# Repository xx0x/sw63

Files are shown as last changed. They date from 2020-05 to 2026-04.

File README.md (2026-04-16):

SW63 Electronic Watch

# Space Watch SW63

Sci-fi inspired electronic watch.

*MK4 in the development, out in 2026.*

## How to tell the time?

When the button is briefly pressed, SW63 tells you the time using a sequence of LED blinks. It's not a binary clock, it's inspired by the analog clock hands movement and uses quarters, halves and so on; similar to how people used to tell the time before the digital clock became popular.
  
**16:35**  
*half past - four - hours - and - five - minutes - PM*

**6:57**  
*three - minutes - to - whole - seven - hours*

Language can be changed in the watch menu to reflect the different ways different languages express the time ("half past five" in English is "half of six" in German etc).

See [LANGUAGES.md](./LANGUAGES.md) for the full list and examples.

## Controls

**Short press:** Show the time  
**Long press:** Enter Menu (setting the language and time)  
**Extra long press:** Enter Secret settings  
**Multiple short presses:** Show animation

*In Menu / Secret settings:*  
**Short press:** Change  
**Long press:** Confirm and go to next

## BOM (DIY Kits)

| Name | Part Number | Qty |
| --- | --- | --- |
| PCB with assembled SMD components | custom part | 1 |
| Red 5 mm LED | LL-503VD2E-V1-4D | 1 |
| Green 5 mm LED | LL-504PGD2E-G5-2B | 1 |
| Blue 5 mm LED | LL-504BD2E-B4-2B | 1 |
| Yellow 5 mm LED | N0Y64L35<br> L-53SYD<br> L-53SYDK | 1 |
| Yellow 3×2 mm LED | LL-234YD2Q-1B | 4 |
| Red 3 mm LED | FYL-3014LRD1A<br> FYL-3014SRT1A | 1 |
| Li-Po battery LP301020 or LP301120* | AKY0471<br> SparkFun 13852<br> SparkFun 25270 | 1 |
| CNC aluminium enclosure | custom part | 1 |
| Screw M1.6 length 4mm (hex socket)  | - | 4 |
| 18 mm watch spring bar | - | 2 |
| 18 mm watch strap | - | 1 |

> [!WARNING]
> \***Note:** Due to the shipping restrictions the Li-Po battery isn't part of the DIY Kit. Please provide your own 40 mAh battery with dimensions 20 mm × 11 mm × 3 mm (or smaller) with the integrated protection circuit.

## License

**Schematics, Hardware Designs**  
CERN-OHL-P-2.0

**Code**  
MIT

**Visual elements, Graphics, Documentation**  
CC BY-SA 4.0

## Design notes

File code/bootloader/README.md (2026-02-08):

# SW63 Bootloader

The bootloader is a separate project created using TinyUF2, source available in [my fork](https://github.com/xx0x/tinyuf2/tree/sw63-bootloader) inside `ports/stm32l0/boards/sw63`.

You can enter the bootloader holding the Button and pressing the Reset. Or double-pressing the Reset if you prefer. Press the Reset again to restart back to the Application.

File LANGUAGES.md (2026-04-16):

# Languages

People have been saying the time in different ways across different languages and countries. Today, many people simply read time in a digital form, like "seventeen twenty-five" or "six forty", mostly because digital clocks are everywhere on our phones, computers, and other screens.

Older time expressions (most significantly in Central Europe languages) were shaped much more by analog clocks and by the way their hands move around the dial. The main differences are which hour the quarter, half, and three-quarter landmarks belong to, and how the sentence is structured around them.

The examples below use 17:25 and 9:17 to show how the same moment is interpreted by each language family. Some of the explanations are a bit of a stretch, but the whole thing is meant as a small experiment. The PM marker, if used, is always last.

Feel free to suggest additional languages and improvements.

## 1. Czech, Slovak, Ukrainian, some east Germany regions

**17:25**  
*before - 5 - minutes - half of - 6 - hours - PM*

**9:17**  
*quarter of - 10 - hours - and - 2 - minutes*

Hour shifts: first quarter = +1 (next hour), half = +1 (next hour), third quarter = +1 (next hour)  
Example: Czech "za pět minut půl šesté"  
Literal meaning: "in five minutes half of six"

## 2. English

**17:25**  
*5 - minutes - before - half past - 5 hours - PM*

**9:17**  
*quarter past - 9 - hours - and - 2 - minutes*

Hour shifts: first quarter = +0 (current hour), half = +0 (current hour), third quarter = +1 (next hour)  
Example: "five minutes before half past five"

## 3. German, Dutch

**17:25**  
*5 - minutes - before - half of - 6 - hours - PM*

**9:17**  
*quarter past - 9 - hours - and - 2 - minutes*

Hour shift: first quarter = +0 (current hour), half = +1 (next hour), third quarter = +1 (next hour)  
Examples: German "fünf vor halb sechs", Dutch "vijf voor half zes"  
Literal meaning: "five before half six"

## 4. Polish

**17:25**  
*before - 5 - minutes - half of - 6 - hours - PM*

**9:17**  
*2 - minutes - after - quarter past - 9 - hours*

Hour shift: first quarter = +0 (current hour), half = +1 (next hour), third quarter = +1 (next hour)  
Example: "za pięć wpół do szóstej"  
Literal meaning: "in five, half to six"

## 5. Hungarian

**17:25**  
*5 - minutes - before - half of - 6 - hours - PM*

**9:17**  
*and - 2 - minutes - quarter of - 10 - hours*

Hour shift: first quarter = +1 (next hour), half = +1 (next hour), third quarter = +1 (next hour)  
Example: "öt perc múlva fél hat"  
Literal meaning: "in five minutes, half six"

## 6. Danish, Norwegian, Swedish, Finnish

**17:25**  
*5 - minutes - before - half of - 6 - hours - PM*

**9:17**  
*2 - minutes - after - quarter past - 9 - hours*

Hour shift: first quarter = +0 (current hour), half = +1 (next hour), third quarter = +1 (next hour)  
Example: Danish "fem i halv seks" / "fem minutter i halv seks"  
Literal meaning: approximately "five into half six"

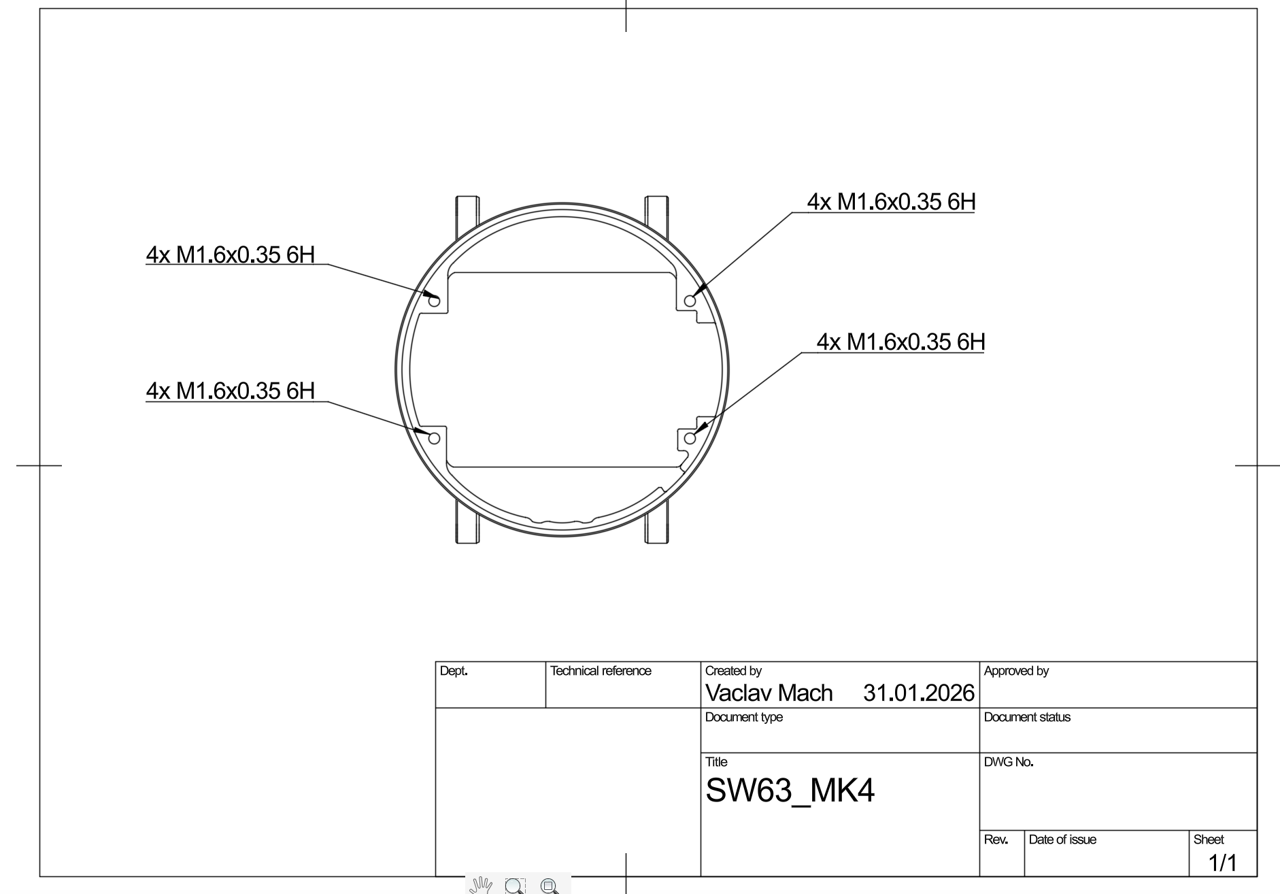
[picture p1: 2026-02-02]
case/sw63-case-threads.png

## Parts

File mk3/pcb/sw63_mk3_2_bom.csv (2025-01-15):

Comment | Designator | Footprint | LCSC Part #
 | PM | LED_3MM_ALT
 | HOURS | LED_5MM_BLUE
 | PLUS | LED_5MM_GREEN
 | MINUS | LED_5MM_RED
 | MINUTES | LED_5MM_YELLOW
1N5819 | D1 | SOD123
1u | C9 | CAPACITOR0603
2X3POGONO_VIA | SWD | 2X3_POGO_NO_VIA
2k | R9 | RESISTOR0603
4k7 | R5 R6 | RESISTOR0603
5k1 | R1 R2 R12 | RESISTOR0603
10k | R3 R4 R7 R8 R10 R13 R14 | RESISTOR0603
10u | C1 C2 C3 C4 | CAPACITOR0805
100n | C5 C6 C7 C8 C10 C11 | CAPACITOR0603
2302 | Q2 | SOT23
2305 | Q1 | SOT23
ATSAMD21E18A-MU | U1 | QFN50P500X500X100-33N
BSMD0805-050-24V | F1 | PTC0805
DS3231MZ+ | U2 | SO8
GT-USB-7070C | J1 | USB-C_FULL_SMT_WS
KSC321JLFS | SW1 | KSC3XXJ
LED_RECT-3.2X2 | DOWN LEFT RIGHT UP | LED_RECT_3.2X2
LED_SMT_1206 | LD1 LD2 LD3 LD4 LD5 LD6 LD7 LD8 LD9 LD10 LD11 LD12 | LED_1206
MCP73832T-2ACI/OT | U7 | SOT23-5
ME6211C33M5G-N | U6 | SOT23-5
RB521S | D2 D3 D4 D5 | SOD523
SMALL_NC | SJ1 | SMALL_NC_NOSILK
TEMT6200FX01 | Q4 | TEMT6200FX01
TEST_PIN_LARGE | B+ B- | TEST_PIN_2.0
TLC5916IPW | U3 U4 U5 | TSSOP16
TSC4A 160gf-WZ 016 | SW2 | EVQ-P7J01P

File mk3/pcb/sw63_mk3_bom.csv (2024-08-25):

Comment | Designator | Footprint | LCSC Part #
 | PM | LED_3MM_ALT
 | HOURS | LED_5MM_BLUE
 | PLUS | LED_5MM_GREEN
 | MINUS | LED_5MM_RED
 | MINUTES | LED_5MM_YELLOW
1N5819 | D1 | SOD123
1u | C9 | CAPACITOR0603
2X3POGONO_VIA | SWD | 2X3_POGO_NO_VIA
2k | R9 | RESISTOR0603
4k7 | R5 R6 | RESISTOR0603
5k1 | R1 R2 R12 | RESISTOR0603
10k | R3 R4 R7 R8 R10 R11 R13 R14 | RESISTOR0603
10u | C1 C2 C3 C4 | CAPACITOR0805
100n | C5 C6 C7 C8 C10 C11 | CAPACITOR0603
500mA | F1 | PTC0805
ATSAMD21E18A-MU | U1 | QFN50P500X500X100-33N
BC817S | Q2 Q3 | SOT23
DS3231MZ+ | U2 | SO8
EVQ-P7J01P | SW2 | EVQ-P7J01P
KSC321JLFS | SW1 | KSC3XXJ
LED_RECT-3.2X2 | DOWN LEFT RIGHT UP | LED_RECT_3.2X2
LED_SMT_1206 | LD1 LD2 LD3 LD4 LD5 LD6 LD7 LD8 LD9 LD10 LD11 LD12 | LED_1206
LGE2305 | Q1 | SOT23
MCP73832T-2ACI/OT | U7 | SOT23-5
MIC5504YM5-TR | U6 | SOT23-5
TEMT6200FX01 | Q4 | TEMT6200FX01
TEST_PIN_LARGE | B+ B- | TEST_PIN_2.0
TLC5916IPW | U3 U4 U5 | TSSOP16
USB-C_2.0_SMT | J1 | USB-C_FULL_SMT

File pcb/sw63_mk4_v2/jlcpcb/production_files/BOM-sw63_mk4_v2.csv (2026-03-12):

Comment | Designator | Footprint | LCSC | Quantity
0603L020/30XR | F1 | Fuse_0603_1608Metric | C20608677 | 1
100k | R11,R12 | R_0402_1005Metric | C25741 | 2
100n | C10,C11,C12,C4,C5,C6,C9 | C_0402_1005Metric | C1525 | 7
10k | R4,R5,R6,R7 | R_0402_1005Metric | C25744 | 4
10u | C1,C2,C3,C7,C8 | C_0402_1005Metric | C315248 | 5
220k | R13 | R_0402_1005Metric | C25767 | 1
22k | R14,R15,R16,R3 | R_0402_1005Metric | C25768 | 4
2k | R8 | R_0402_1005Metric | C4109 | 1
5k1 | R1,R10,R2,R9 | R_0402_1005Metric | C25905 | 4
DIO5518BST5 | U1 | SOT-23-5 | C38066 | 1
DMG2302U-7 | Q2 | SOT-23 | C96613 | 1
DMG2305UX-7 | Q1 | SOT-23 | C150470 | 1
DS3231MZ | U6 | SOIC-8_3.9x4.9mm_P1.27mm | C107410 | 1
GT-USB-7070C | J1 | GT-USB-7070C | C5446864 | 1
KSC321J LFS | SW1 | SW_Push_1P1T_NO_CK_KSC3xxJ | C2798494 | 1
LED | D1,D10,D11,D12,D2,D3,D4,D5,D6,D7,D8,D9 | LED_1206_W | C965828 | 12
MCP1711T-3.3I/OT | U2 | SOT-23-5 | C79527 | 1
MS2A40LWS | D22 | D_SOD-323 | C7380001 | 1
STM32L052K8Ux | U7 | QFN-32-1EP_5x5mm_P0.5mm_EP3.45x3.45mm | C1342049 | 1
TEMT6200FX01 | Q3 | TEMT6200FX01 | C143695 | 1
TLC5916IPWR | U3,U4,U5 | TSSOP-16_4.4x5mm_P0.65mm | C193571 | 3
EVQ-P7J01P | SW2 | SW_SPST_EVQP7A | C2828254 | 1
LED | D14 | LED_D5.0mm_B |  | 1
LED | D16 | LED_D5.0mm_R |  | 1
LED | D21 | LED_D3.0mm_R |  | 1
LED | D20 | LED_W3.0mm_H2.0mm_Y |  | 1
LED | D18 | LED_W3.0mm_H2.0mm_Y |  | 1
LED | D13 | LED_D5.0mm_Y |  | 1
LED | D15 | LED_D5.0mm_G |  | 1
LED | D19 | LED_W3.0mm_H2.0mm_Y |  | 1
Conn_01x02 | J3 | BAT |  | 1
LED | D17 | LED_W3.0mm_H2.0mm_Y |  | 1

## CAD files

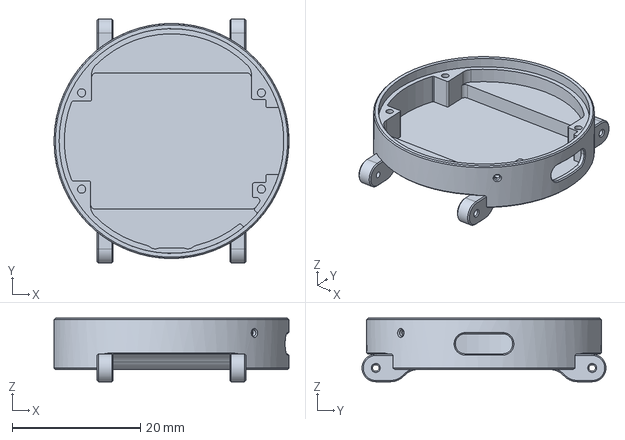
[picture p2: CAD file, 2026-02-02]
case/sw63-case.step
36.6 x 38.0 x 9.90 mm

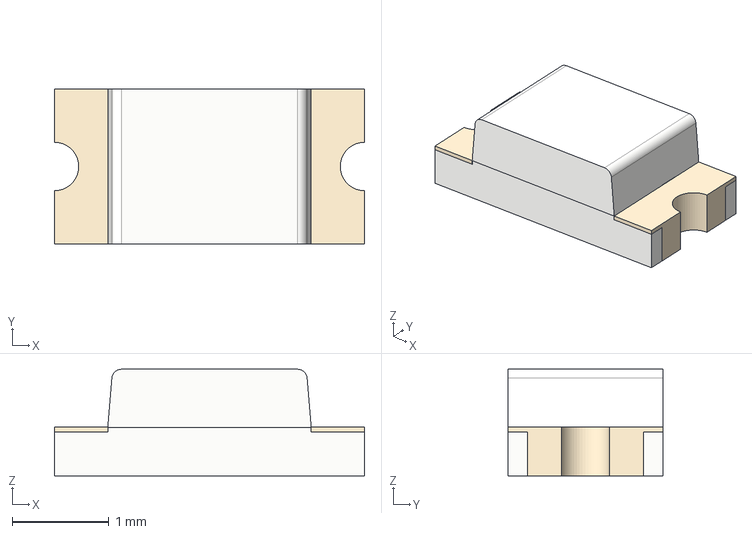
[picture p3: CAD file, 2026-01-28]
pcb/sw63_mk4_v2/3d_models/LED_1206_W.step
3.20 x 1.60 x 1.10 mm

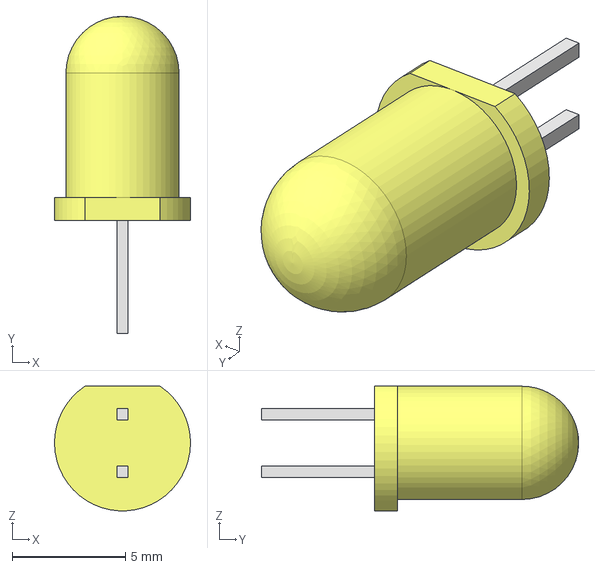
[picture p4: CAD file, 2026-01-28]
pcb/sw63_mk4_v2/3d_models/LED_5mm_Y.step
6.00 x 14.0 x 5.49 mm

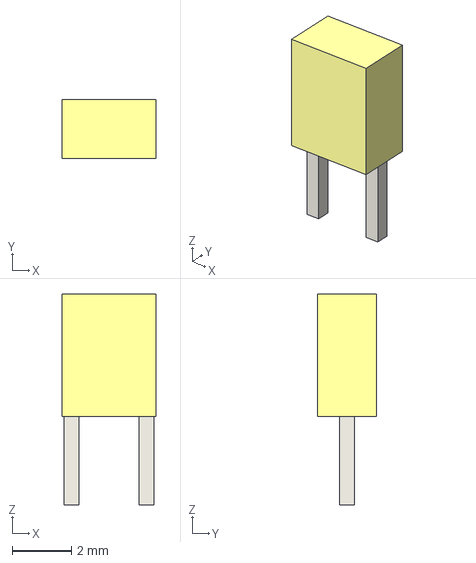
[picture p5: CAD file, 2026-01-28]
pcb/sw63_mk4_v2/3d_models/LED_2x3mm_Y.step
3.20 x 2.00 x 7.15 mm

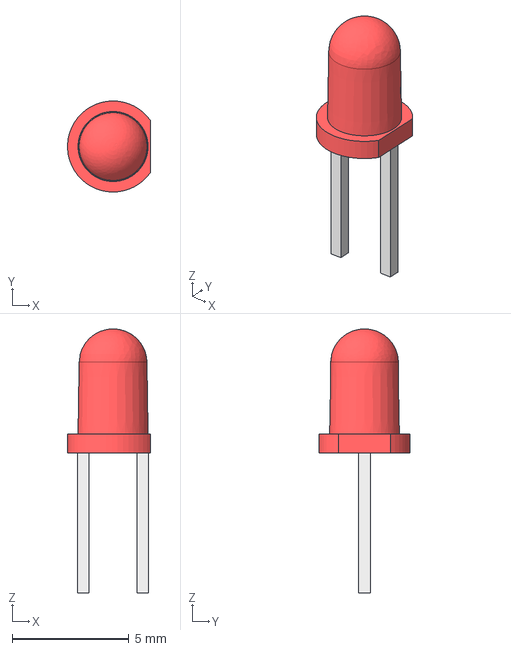
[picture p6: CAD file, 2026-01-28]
pcb/sw63_mk4_v2/3d_models/LED_3mm_R.step
3.55 x 3.90 x 11.3 mm
Деталь1
Деталь2 x 2

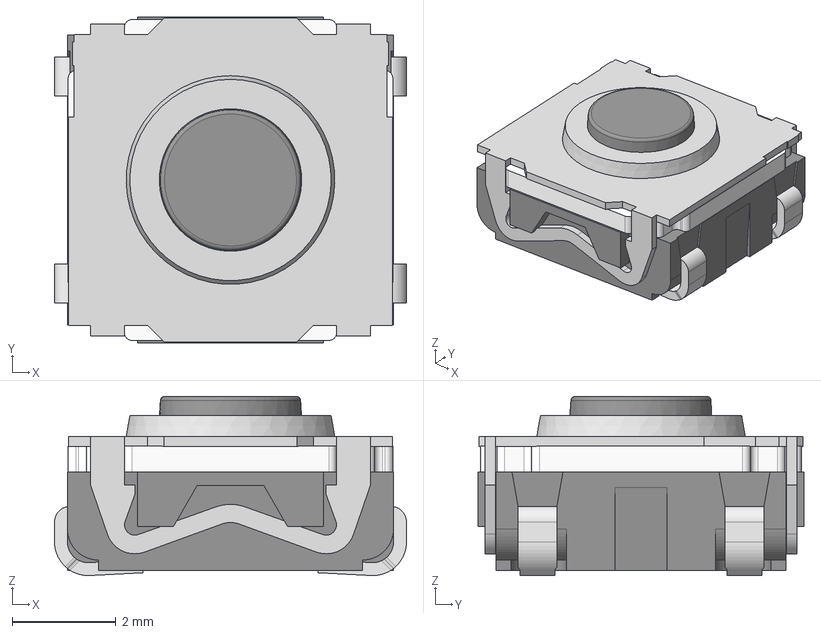
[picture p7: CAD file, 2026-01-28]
pcb/sw63_mk4_v2/3d_models/KSC3XXJ.step
6.80 x 6.30 x 3.46 mm
KSC3_body
KSC3_button
KSC3_cover
KSC31J_pin x 4

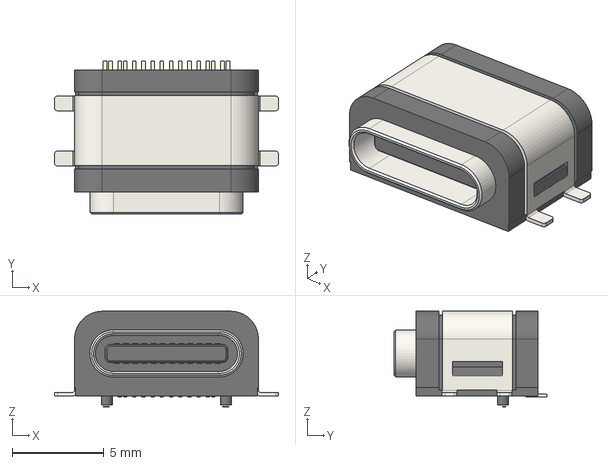
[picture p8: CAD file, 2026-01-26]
pcb/sw63_mk4_v2/3d_models/GT-USB-7070C.step
12.2 x 8.35 x 5.20 mm

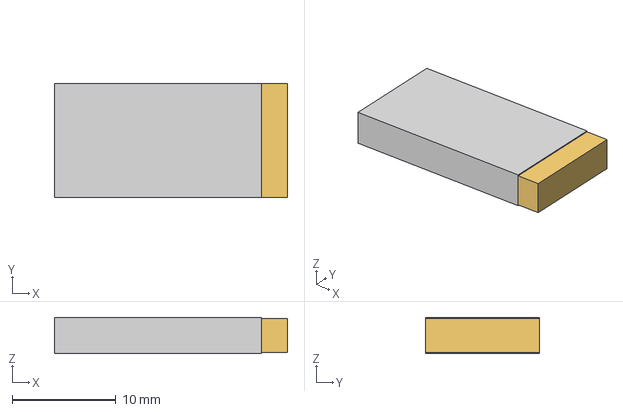
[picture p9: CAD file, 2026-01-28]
pcb/sw63_mk4_v2/3d_models/LP301020.step
22.5 x 11.0 x 3.50 mm

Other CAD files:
pcb/sw63_mk4_v2/3d_models/LED_5mm_G.step
pcb/sw63_mk4_v2/3d_models/LED_5mm_R.step
pcb/sw63_mk4_v2/3d_models/LED_5mm_B.step

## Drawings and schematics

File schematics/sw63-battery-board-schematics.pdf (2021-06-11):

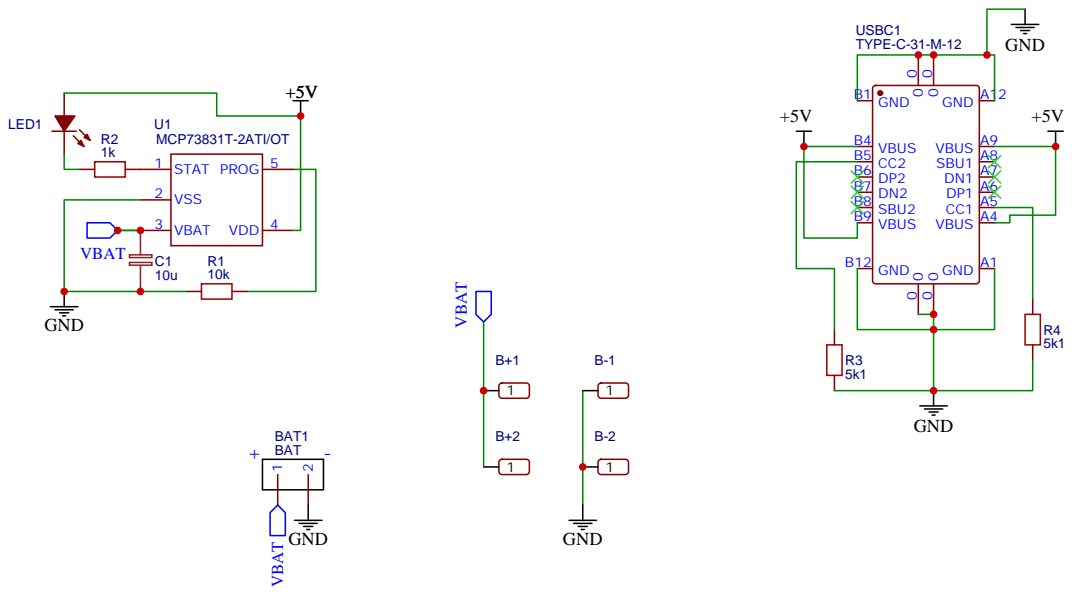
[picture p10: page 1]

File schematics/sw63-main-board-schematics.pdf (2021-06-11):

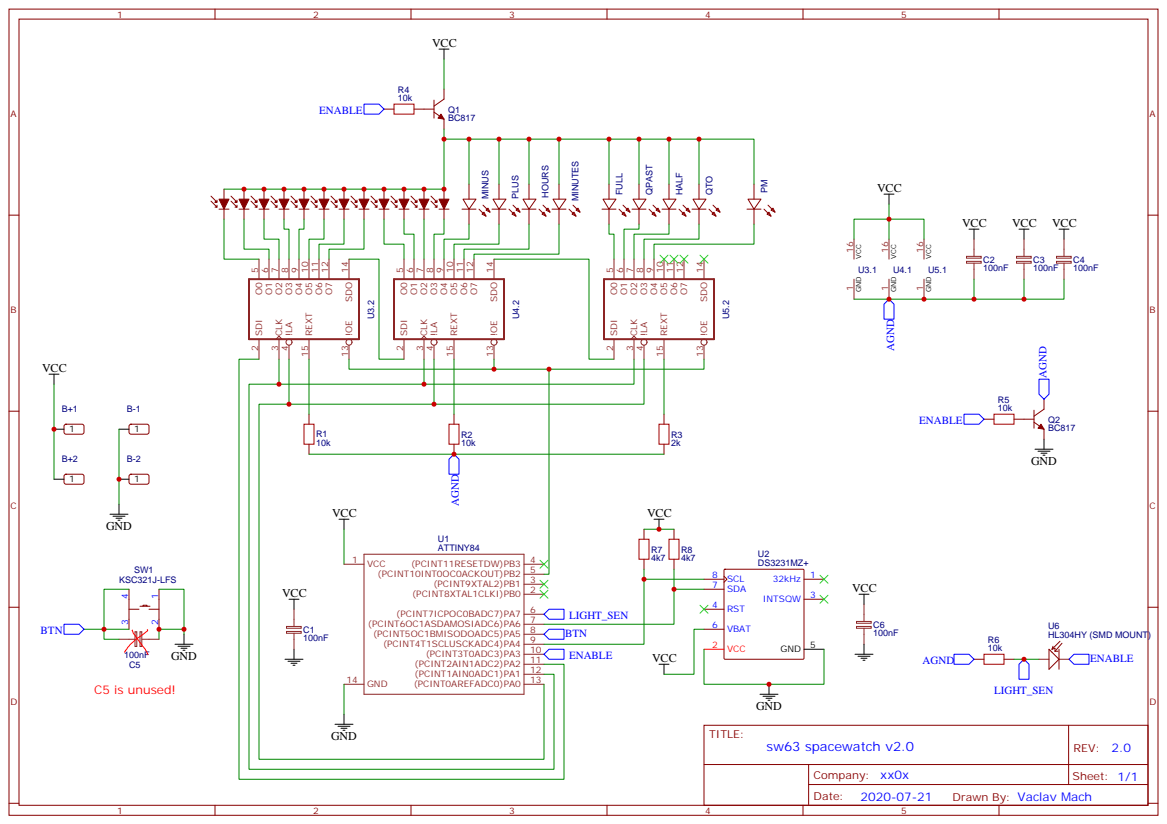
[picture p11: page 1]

Drawn By: Vaclav Mach

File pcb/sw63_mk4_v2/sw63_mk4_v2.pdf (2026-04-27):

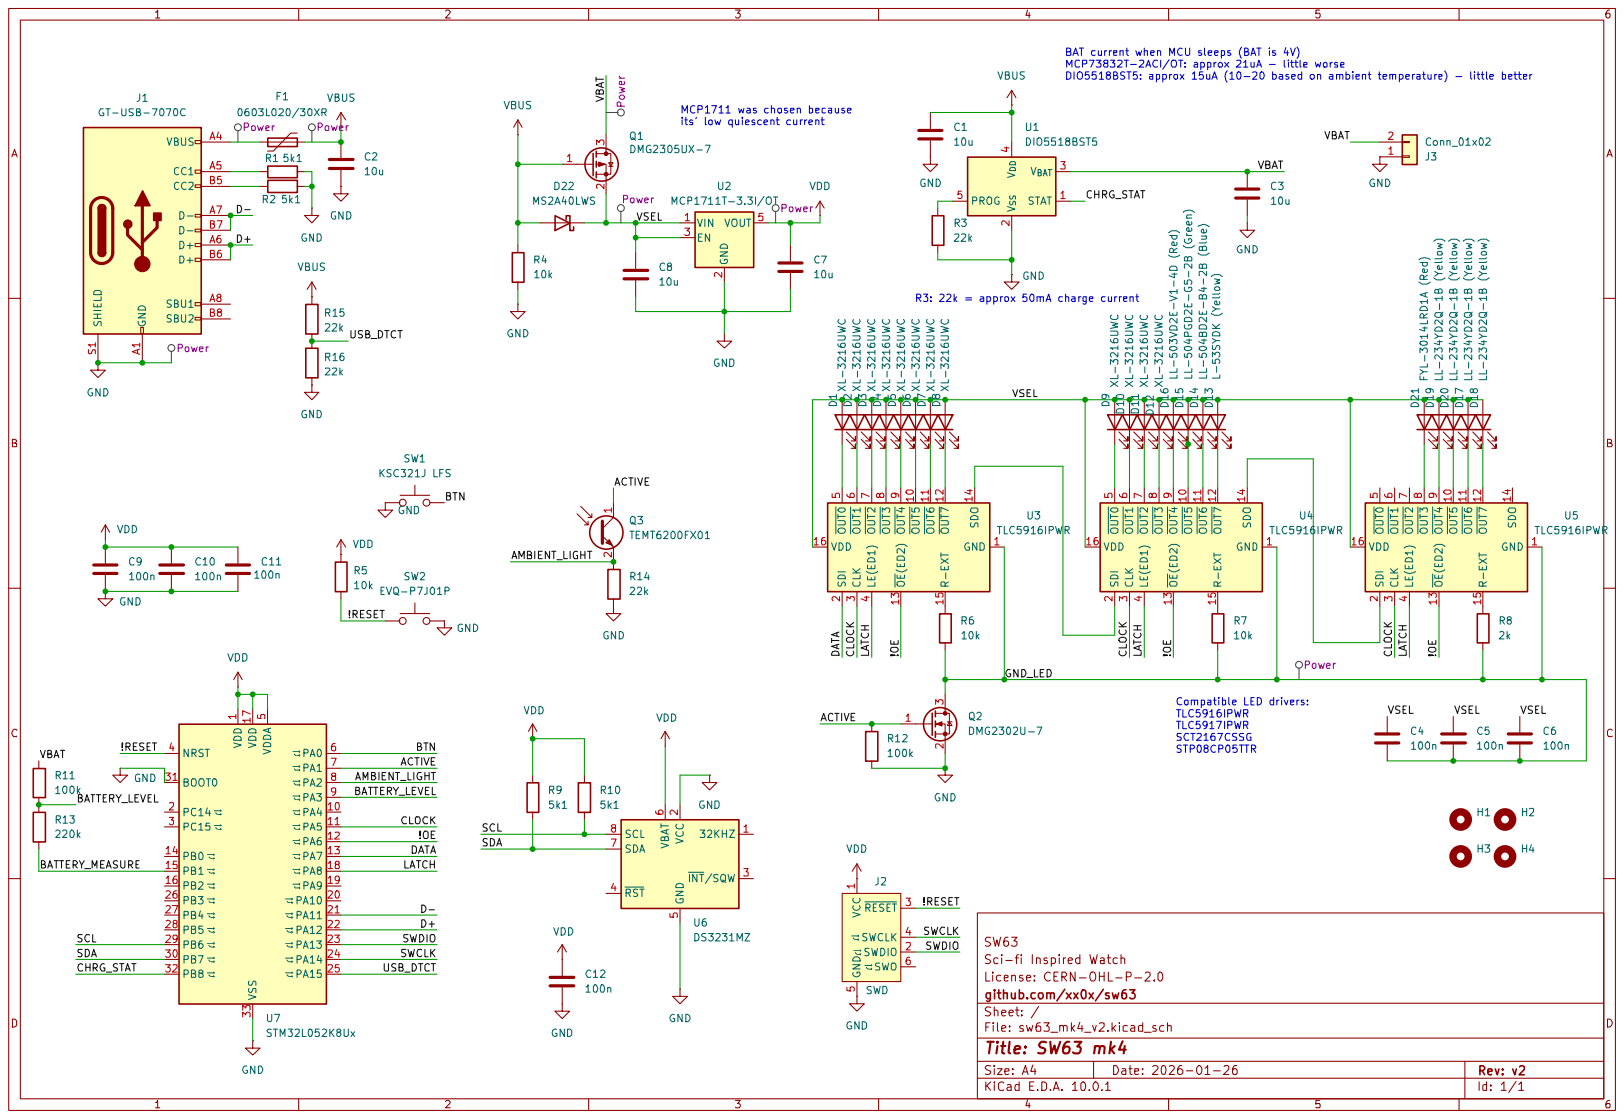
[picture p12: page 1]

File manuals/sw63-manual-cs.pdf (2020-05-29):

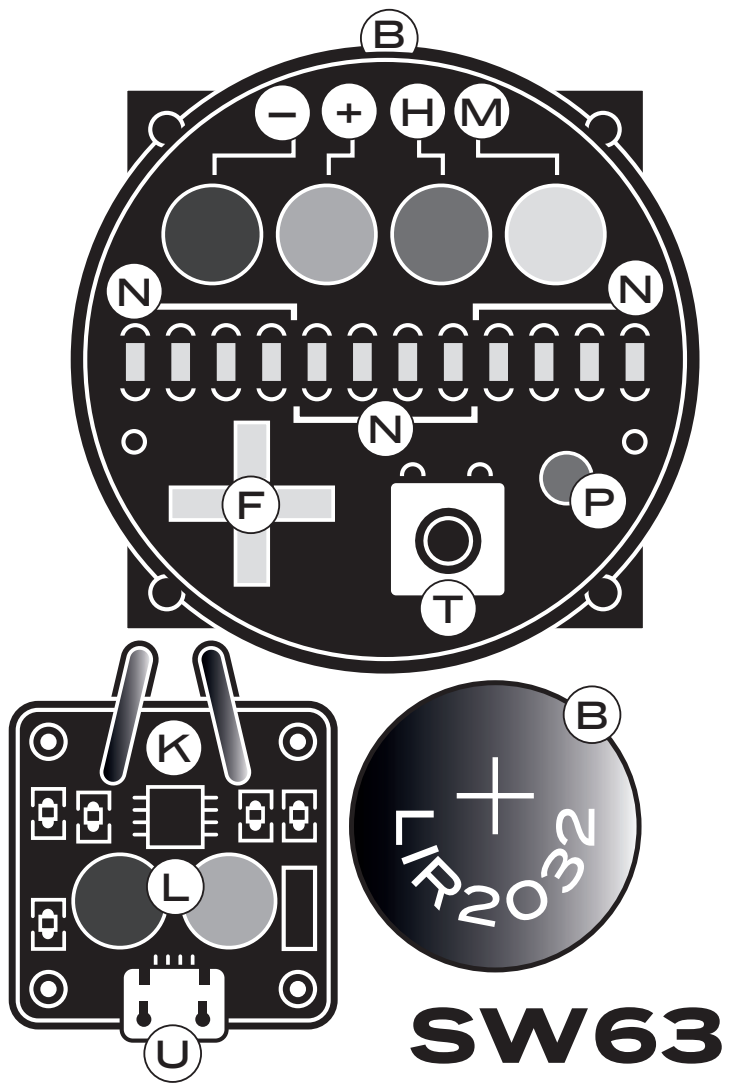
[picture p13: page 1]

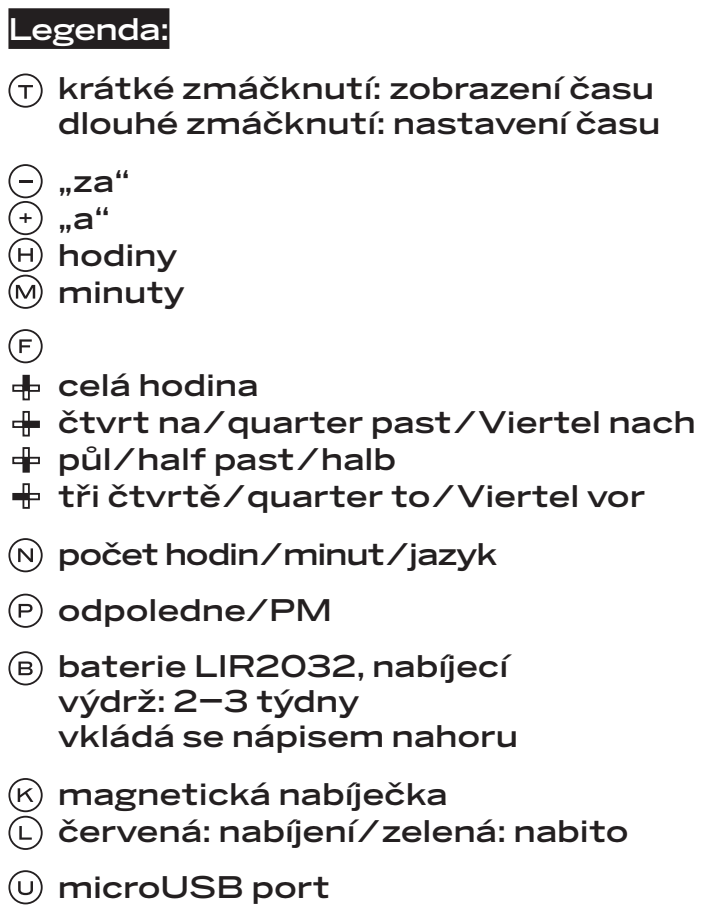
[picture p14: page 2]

Legenda:
krátké zmáčknutí: zobrazení času
dlouhé zmáčknutí: nastavení času
hodiny
minuty

celá hodina
čtvrt na/quarter past/Viertel nach
půl/half past/halb
tři čtvrtě/quarter to/Viertel vor
počet hodin/minut/jazyk
odpoledne/PM
baterie LIR2032, nabíjecí
výdrž: 2–3 týdny
vkládá se nápisem nahoru
magnetická nabíječka
červená: nabíjení/zelená: nabito
microUSB port

SW63 - SPACEWATCH
Hodinky SPACEWATCH zobrazují čas pomocí lidské řeči. 17:28 se zobrazí jako: „za–dvě–minuty–půl–šesté–odpoledne“

Odolnost a údržba:
Hodinkám nevadí drobné kapky od mytí rukou nebo slabého deště, při větším namočení je vhodné vytáhnout baterii
a hodinky nechat vyschnout.
Zaprášené nebo jinak znečištěné hodinky lze otřít vatovou štětičkou namočenou v destilované vodě.

Intro animace:
Pro rozblikání hodinek několikrát po sobě rychle zmáčknout .
Na konci intro animace zabliká aktuálně zvolený jazyk, poté se zobrazí čas.

xx0x.cz
info@xx0x.cz
@xx0x.cz

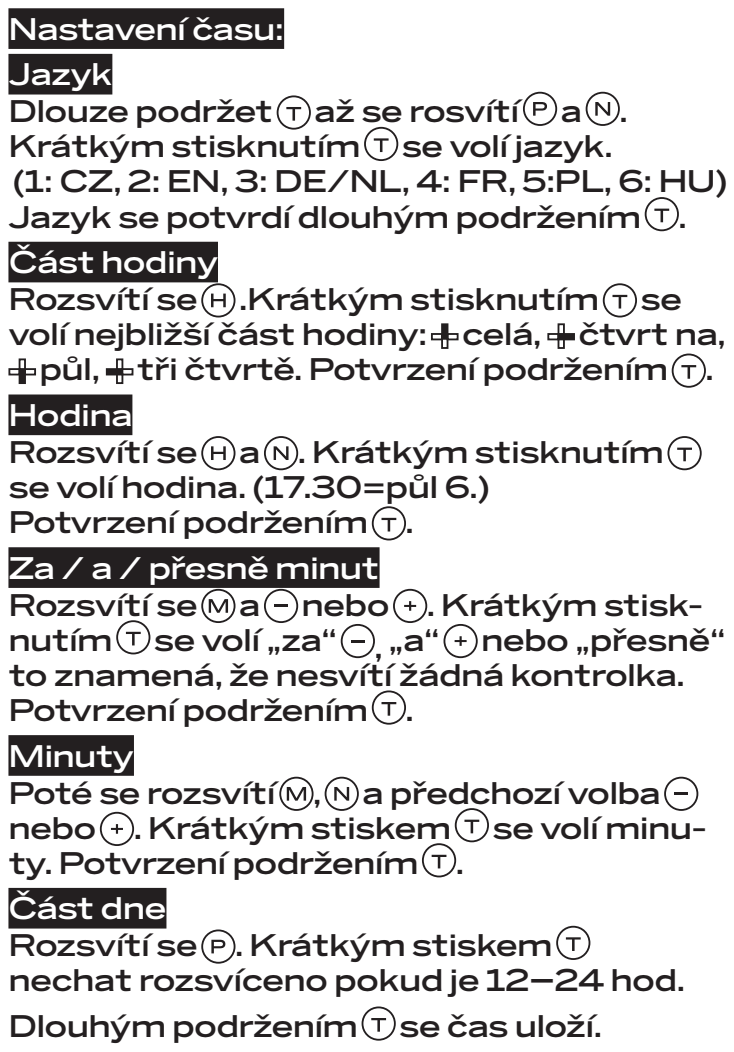
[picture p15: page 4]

Nastavení času:
Jazyk
Dlouze podržet až se rosvítí a .
Krátkým stisknutím se volí jazyk.
Jazyk se potvrdí dlouhým podržením .
Část hodiny
Rozsvítí se .Krátkým stisknutím se
volí nejbližší část hodiny: celá, čtvrt na,
půl, tři čtvrtě. Potvrzení podržením .
Hodina
Rozsvítí se a . Krátkým stisknutím
se volí hodina. (17.30=půl 6.)
Potvrzení podržením .
Za / a / přesně minut
Rozsvítí se a nebo . Krátkým stisk-
nutím se volí „za“ , „a“ nebo „přesně“
to znamená, že nesvítí žádná kontrolka.
Minuty
Poté se rozsvítí , a předchozí volba
nebo . Krátkým stiskem se volí minu-
ty. Potvrzení podržením .
Část dne
Rozsvítí se . Krátkým stiskem
nechat rozsvíceno pokud je 12–24 hod.
Dlouhým podržením se čas uloží.

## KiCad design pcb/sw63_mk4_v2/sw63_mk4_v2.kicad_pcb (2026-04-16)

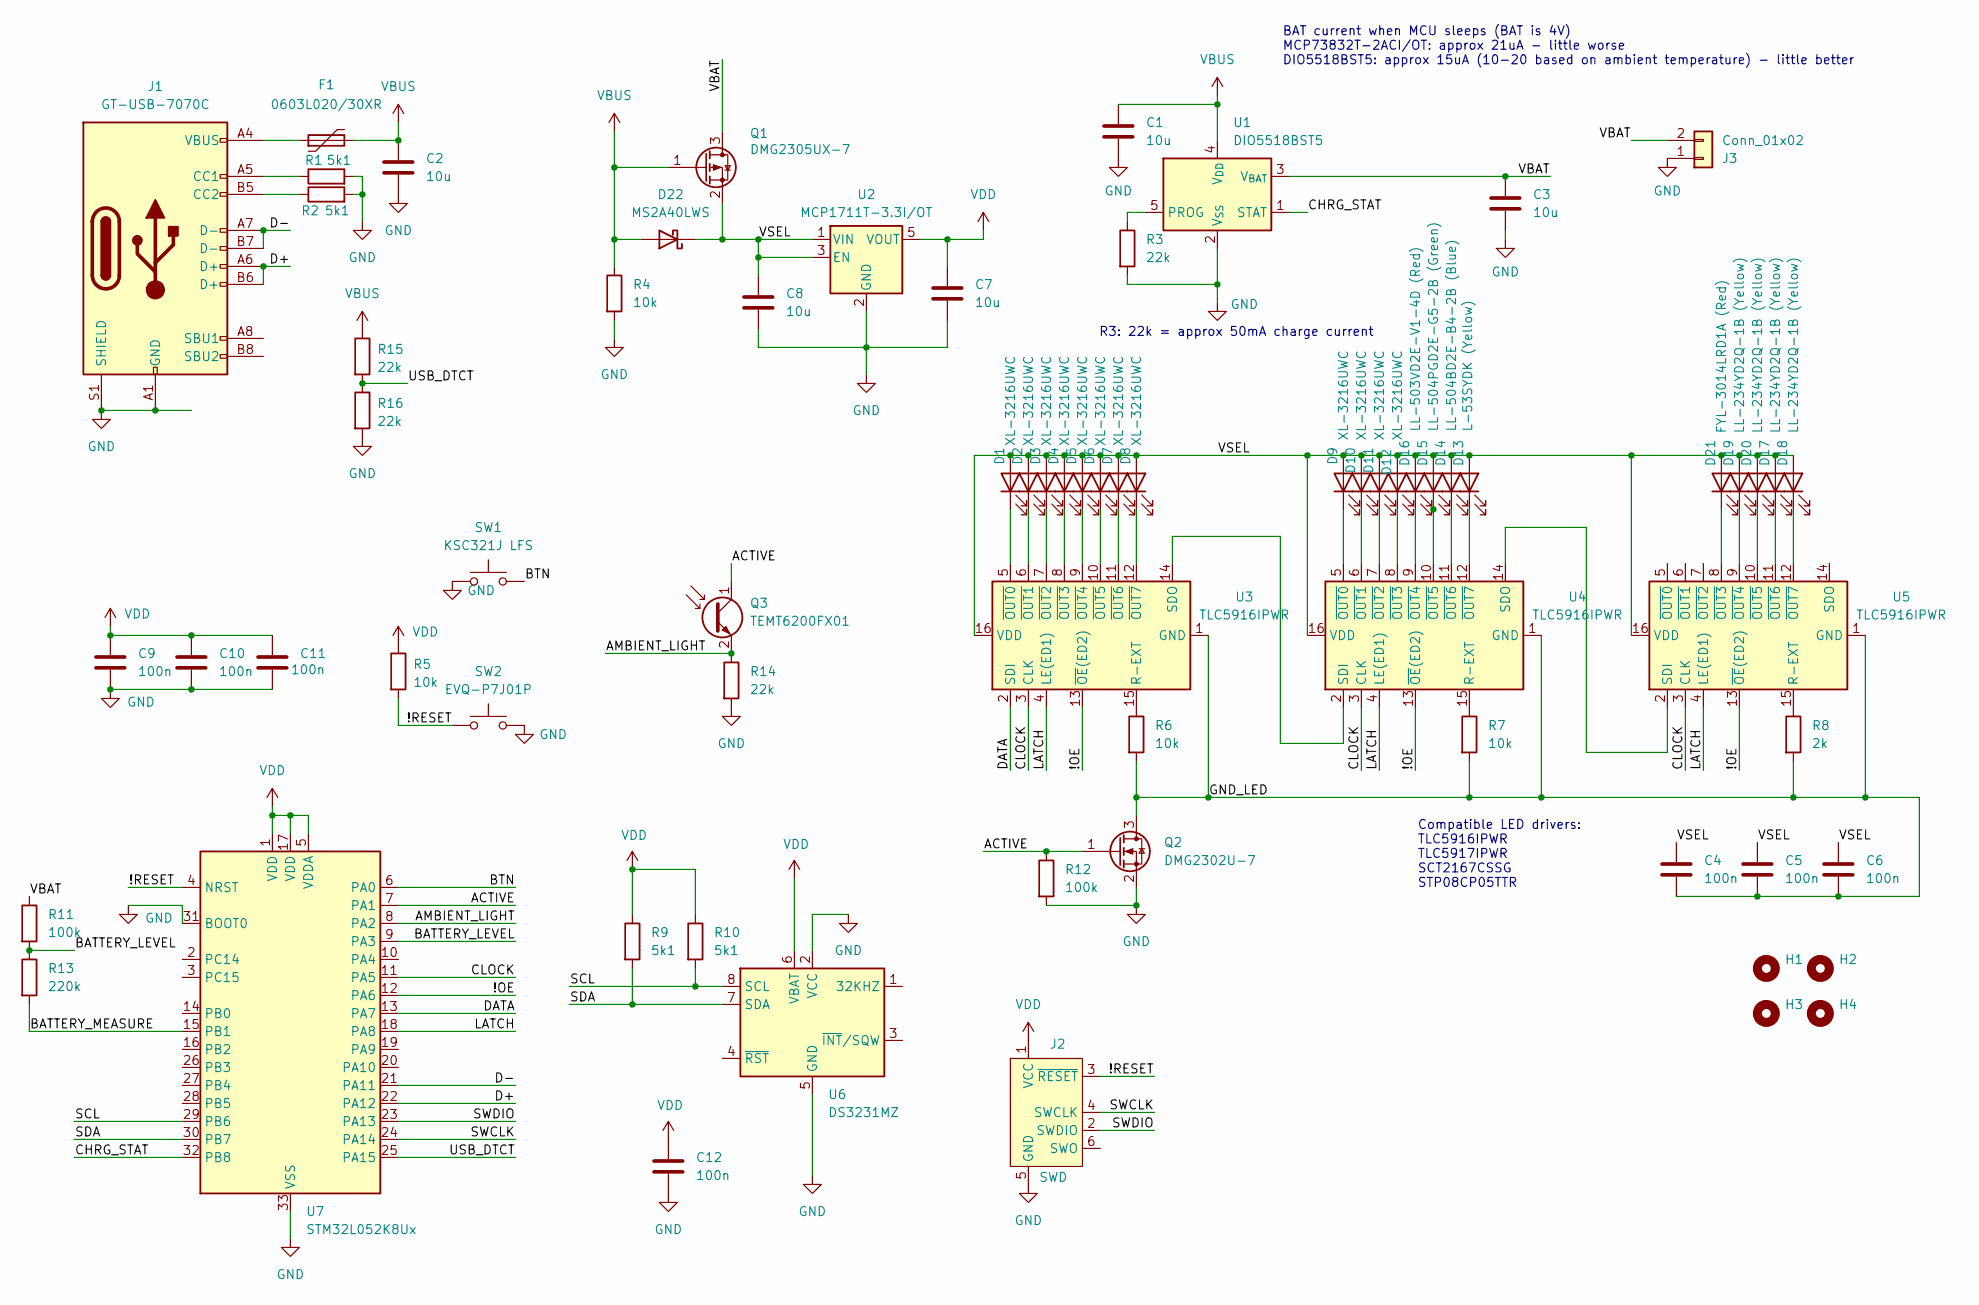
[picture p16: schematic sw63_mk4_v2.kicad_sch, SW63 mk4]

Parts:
C1, C2, C3, C7, C8: 10u; C_0402_1005Metric; LCSC C315248
C4, C5, C6, C9, C10, C11, C12: 100n; C_0402_1005Metric; LCSC C1525
D1, D2, D3, D4, D5, D6, D7, D8, D9, D10, D11, D12: XL-3216UWC; LED_1206_W; LCSC C965828
D13: L-53SYDK (Yellow); LED_D5.0mm_Y
D14: LL-504BD2E-B4-2B (Blue); LED_D5.0mm_B
D15: LL-504PGD2E-G5-2B (Green); LED_D5.0mm_G
D16: LL-503VD2E-V1-4D (Red); LED_D5.0mm_R
D17, D18, D19, D20: LL-234YD2Q-1B (Yellow); LED_W3.0mm_H2.0mm_Y
D21: FYL-3014LRD1A (Red); LED_D3.0mm_R
D22: MS2A40LWS; D_SOD-323; LCSC C7380001
F1: 0603L020/30XR; Fuse_0603_1608Metric; LCSC C20608677
H1, H2, H3, H4: MountingHole; MountingHole_1.6mm
J1: GT-USB-7070C; LCSC C5446864
J2: SWD; SWD_2x03_SMD
J3: Conn_01x02; BAT
Q1: DMG2305UX-7; SOT-23; LCSC C150470
Q2: DMG2302U-7; SOT-23
Q3: TEMT6200FX01; LCSC C143695
R1, R2, R9, R10: 5k1; R_0402_1005Metric; LCSC C25905
R3, R14, R15, R16: 22k; R_0402_1005Metric; LCSC C25768
R4, R5, R6, R7: 10k; R_0402_1005Metric; LCSC C25744
R8: 2k; R_0402_1005Metric; LCSC C4109
R11, R12: 100k; R_0402_1005Metric; LCSC C25741
R13: 220k; R_0402_1005Metric; LCSC C25767
SW1: KSC321J LFS; SW_Push_1P1T_NO_CK_KSC3xxJ; LCSC C2798494
SW2:  EVQ-P7J01P; SW_SPST_EVQP7A; LCSC C2828254
U1: DIO5518BST5; SOT-23-5; LCSC C38066
U2: MCP1711T-3.3I/OT; SOT-23-5; LCSC C79527
U3, U4, U5: TLC5916IPWR; TSSOP-16_4.4x5mm_P0.65mm; LCSC C193571
U6: DS3231MZ; SOIC-8_3.9x4.9mm_P1.27mm; LCSC C107410
U7: STM32L052K8Ux; QFN-32-1EP_5x5mm_P0.5mm_EP3.45x3.45mm; LCSC C1342049

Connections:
/!OE: U3.13 (~OE(ED2)), U4.13 (~OE(ED2)), U5.13 (~OE(ED2)), U7.12 (PA6)
/!RESET: J2.3 (~RESET), R5.2, SW2.1, U7.4 (NRST)
/ACTIVE: Q2.1 (G), Q3.1 (C), R12.1, U7.7 (PA1)
/AMBIENT_LIGHT: Q3.2 (E), R14.1, U7.8 (PA2)
/BATTERY_LEVEL: R11.2, R13.1, U7.9 (PA3)
/BATTERY_MEASURE: R13.2, U7.15 (PB1)
/BTN: SW1.2, U7.6 (PA0)
/CHRG_STAT: U1.1 (STAT), U7.32 (PB8)
/CLOCK: U3.3 (CLK), U4.3 (CLK), U5.3 (CLK), U7.11 (PA5)
/D+: J1.A6 (D+), J1.B6 (D+), U7.22 (PA12)
/D-: J1.A7 (D-), J1.B7 (D-), U7.21 (PA11)
/DATA: U3.2 (SDI), U7.13 (PA7)
/GND_LED: C4.2, C5.2, C6.2, Q2.3 (D), R6.2, R7.2, R8.2, U3.1 (GND), U4.1 (GND), U5.1 (GND)
/LATCH: U3.4 (LE(ED1)), U4.4 (LE(ED1)), U5.4 (LE(ED1)), U7.18 (PA8)
/SCL: R10.2, U6.8 (SCL), U7.29 (PB6)
/SDA: R9.2, U6.7 (SDA), U7.30 (PB7)
/SWCLK: J2.4 (SWCLK), U7.24 (PA14)
/SWDIO: J2.2 (SWDIO), U7.23 (PA13)
/USB_DTCT: R15.2, R16.1, U7.25 (PA15)
/VBAT: C3.1, J3.2, Q1.3 (D), R11.1, U1.3 (V_{BAT})
/VSEL: C4.1, C5.1, C6.1, C8.1, D1.2 (A), D2.2 (A), D3.2 (A), D4.2 (A), D5.2 (A), D6.2 (A), D7.2 (A), D8.2 (A), D9.2 (A), D10.2 (A), D11.2 (A), D12.2 (A), D13.2 (A), D14.2 (A), D15.2 (A), D16.2 (A), D17.2 (A), D18.2 (A), D19.2 (A), D20.2 (A), D21.2 (A), D22.1 (K), Q1.2 (S), U2.1 (VIN), U2.3 (EN), U3.16 (VDD), U4.16 (VDD), U5.16 (VDD)
GND: C1.2, C2.2, C3.2, C7.2, C8.2, C9.2, C10.2, C11.2, C12.2, J1.A1 (GND), J1.A12 (GND), J1.B1 (GND), J1.B12 (GND), J1.S1 (SHIELD), J2.5 (GND), J3.1, Q2.2 (S), R1.2, R2.2, R3.2, R4.2, R12.2, R14.2, R16.2, SW1.1, SW2.2, U1.2 (V_{SS}), U2.2 (GND), U6.2 (VCC), U6.5 (GND), U7.31 (BOOT0), U7.33 (VSS)
unnamed: D1.1 (K), U3.5 (~OUT0)
unnamed: D2.1 (K), U3.6 (~OUT1)
unnamed: D3.1 (K), U3.7 (~OUT2)
unnamed: D4.1 (K), U3.8 (~OUT3)
unnamed: D5.1 (K), U3.9 (~OUT4)
unnamed: D6.1 (K), U3.10 (~OUT5)
unnamed: D7.1 (K), U3.11 (~OUT6)
unnamed: D8.1 (K), U3.12 (~OUT7)
unnamed: D9.1 (K), U4.5 (~OUT0)
unnamed: D10.1 (K), U4.6 (~OUT1)
unnamed: D11.1 (K), U4.7 (~OUT2)
unnamed: D12.1 (K), U4.8 (~OUT3)
unnamed: D13.1 (K), U4.12 (~OUT7)
unnamed: D14.1 (K), U4.11 (~OUT6)
unnamed: D15.1 (K), U4.10 (~OUT5)
unnamed: D16.1 (K), U4.9 (~OUT4)
unnamed: D17.1 (K), U5.11 (~OUT6)
unnamed: D18.1 (K), U5.12 (~OUT7)
unnamed: D19.1 (K), U5.9 (~OUT4)
unnamed: D20.1 (K), U5.10 (~OUT5)
unnamed: D21.1 (K), U5.8 (~OUT3)
unnamed: F1.1, J1.A4 (VBUS), J1.A9 (VBUS), J1.B4 (VBUS), J1.B9 (VBUS)
unnamed: J1.A5 (CC1), R1.1
unnamed: J1.B5 (CC2), R2.1
unnamed: R3.1, U1.5 (PROG)
unnamed: R6.1, U3.15 (R-EXT)
unnamed: U3.14 (SDO), U4.2 (SDI)
unnamed: R7.1, U4.15 (R-EXT)
unnamed: U4.14 (SDO), U5.2 (SDI)
unnamed: R8.1, U5.15 (R-EXT)
VBUS: C1.1, C2.1, D22.2 (A), F1.2, Q1.1 (G), R4.1, R15.1, U1.4 (V_{DD})
VDD: C7.1, C9.1, C10.1, C11.1, C12.1, J2.1 (VCC), R5.1, R9.1, R10.1, U2.5 (VOUT), U6.6 (VBAT), U7.1 (VDD), U7.5 (VDDA), U7.17 (VDD)

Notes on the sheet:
BAT current when MCU sleeps (BAT is 4V) MCP73832T-2ACI/OT: approx 21uA - little worse DIO5518BST5: approx 15uA (10-20 based on ambient temperature) - little better
R3: 22k = approx 50mA charge current
Compatible LED drivers: TLC5916IPWR TLC5917IPWR SCT2167CSSG STP08CP05TTR

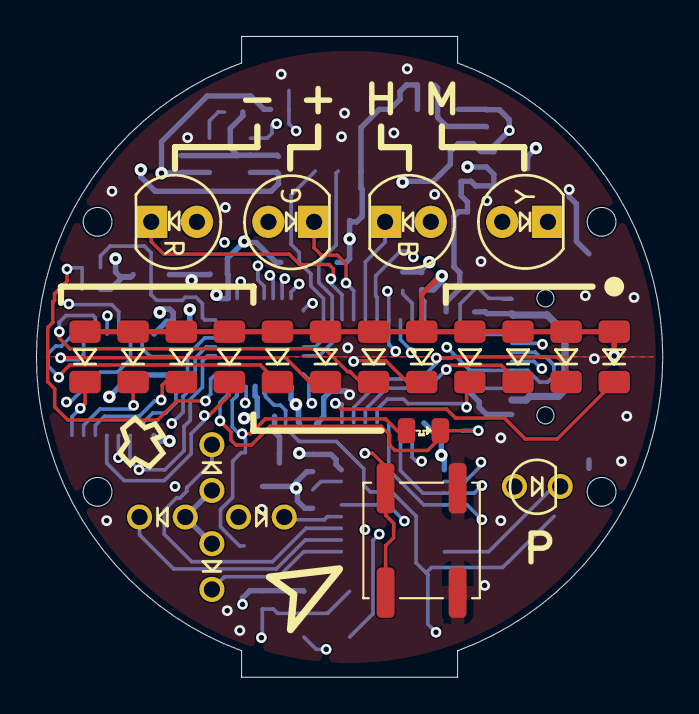
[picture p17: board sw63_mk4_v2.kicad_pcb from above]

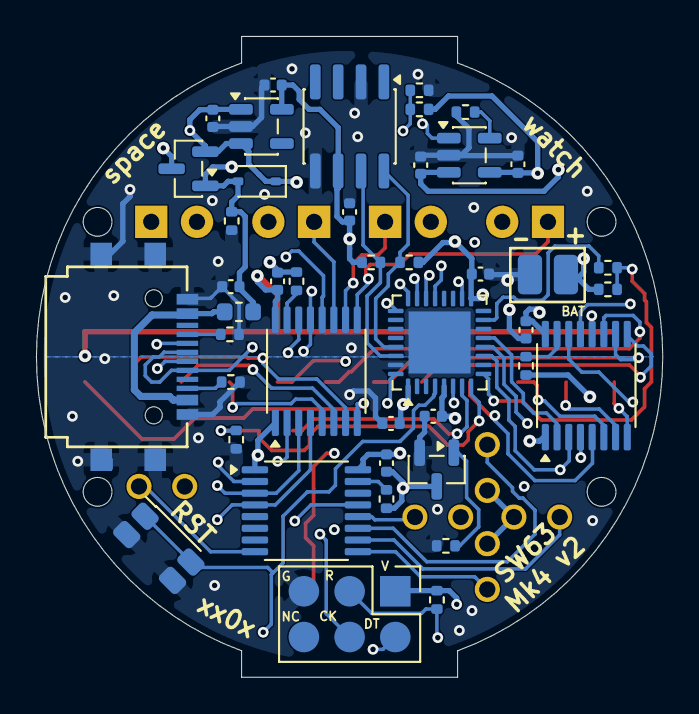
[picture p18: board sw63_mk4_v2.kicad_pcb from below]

Board: 4 copper layers, 34.8 x 35.6 mm, 70 parts (43 on the bottom side), 54 nets.

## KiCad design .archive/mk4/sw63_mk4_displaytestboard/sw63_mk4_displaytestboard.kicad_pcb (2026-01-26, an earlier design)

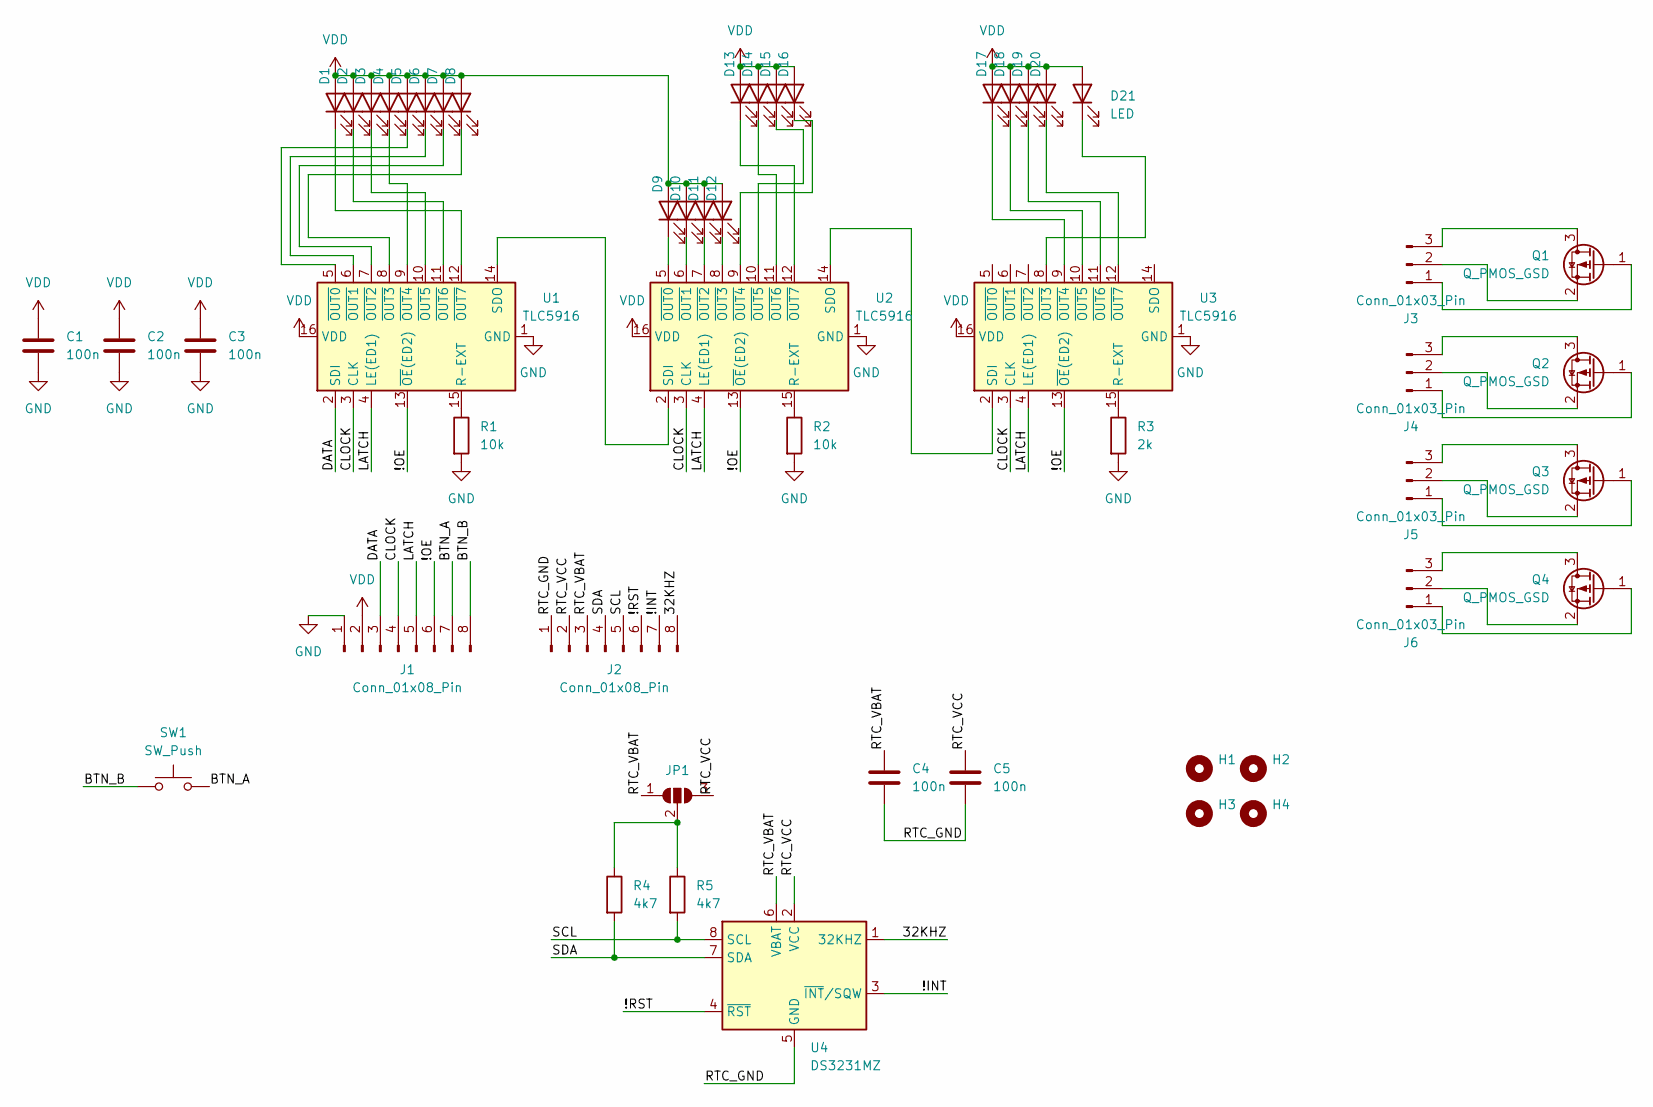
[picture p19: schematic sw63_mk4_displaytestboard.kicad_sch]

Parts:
C1, C2, C3, C4, C5: 100n; C_0603_1608Metric_Pad1.08x0.95mm_HandSolder
D1, D2, D3, D4, D5, D6, D7, D8, D9, D10, D11, D12: LED; LED_1206_3216Metric_Pad1.42x1.75mm_HandSolder
D13, D14, D15, D16: LED; LED_D5.0mm
D17, D18, D19, D20: LED; LED_D2.0mm_W4.0mm_H2.8mm_FlatTop
D21: LED; LED_D3.0mm
H1, H2, H3, H4: MountingHole; MountingHole_3.2mm_M3_DIN965
J1, J2: Conn_01x08_Pin; PinHeader_1x08_P2.54mm_Vertical
J3, J4, J5, J6: Conn_01x03_Pin; PinHeader_1x03_P2.54mm_Vertical
JP1: SolderJumper_3_Open; SolderJumper-3_P2.0mm_Open_TrianglePad1.0x1.5mm
Q1, Q2, Q3, Q4: Q_PMOS_GSD; SOT-23
R1, R2: 10k; R_0603_1608Metric_Pad0.98x0.95mm_HandSolder
R3: 2k; R_0603_1608Metric_Pad0.98x0.95mm_HandSolder
R4, R5: 4k7; R_0603_1608Metric_Pad0.98x0.95mm_HandSolder
SW1: SW_Push; SW_PUSH_6mm
U1, U2, U3: TLC5916; TSSOP-16_4.4x5mm_P0.65mm
U4: DS3231MZ; SOIC-8_3.9x4.9mm_P1.27mm

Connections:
/32KHZ: J2.8, U4.1 (32KHZ)
/!INT: J2.7, U4.3 (~INT/SQW)
/!OE: J1.6, U1.13 (~OE(ED2)), U2.13 (~OE(ED2)), U3.13 (~OE(ED2))
/!RST: J2.6, U4.4 (~RST)
/BTN_A: J1.7, SW1.2
/BTN_B: J1.8, SW1.1
/CLOCK: J1.4, U1.3 (CLK), U2.3 (CLK), U3.3 (CLK)
/DATA: J1.3, U1.2 (SDI)
/LATCH: J1.5, U1.4 (LE(ED1)), U2.4 (LE(ED1)), U3.4 (LE(ED1))
/RTC_GND: C4.2, C5.2, J2.1, U4.5 (GND)
/RTC_VBAT: C4.1, J2.3, JP1.1 (A), U4.6 (VBAT)
/RTC_VCC: C5.1, J2.2, JP1.3 (B), U4.2 (VCC)
/SCL: J2.5, R5.2, U4.8 (SCL)
/SDA: J2.4, R4.2, U4.7 (SDA)
GND: C1.2, C2.2, C3.2, J1.1, R1.2, R2.2, R3.2, U1.1 (GND), U2.1 (GND), U3.1 (GND)
unnamed: D1.1 (K), U1.12 (~OUT7)
unnamed: D2.1 (K), U1.11 (~OUT6)
unnamed: D3.1 (K), U1.10 (~OUT5)
unnamed: D4.1 (K), U1.9 (~OUT4)
unnamed: D5.1 (K), U1.5 (~OUT0)
unnamed: D6.1 (K), U1.6 (~OUT1)
unnamed: D7.1 (K), U1.7 (~OUT2)
unnamed: D8.1 (K), U1.8 (~OUT3)
unnamed: D9.1 (K), U2.5 (~OUT0)
unnamed: D10.1 (K), U2.6 (~OUT1)
unnamed: D11.1 (K), U2.7 (~OUT2)
unnamed: D12.1 (K), U2.8 (~OUT3)
unnamed: D13.1 (K), U2.12 (~OUT7)
unnamed: D14.1 (K), U2.11 (~OUT6)
unnamed: D15.1 (K), U2.10 (~OUT5)
unnamed: D16.1 (K), U2.9 (~OUT4)
unnamed: D17.1 (K), U3.9 (~OUT4)
unnamed: D18.1 (K), U3.10 (~OUT5)
unnamed: D19.1 (K), U3.11 (~OUT6)
unnamed: D20.1 (K), U3.12 (~OUT7)
unnamed: D21.1 (K), U3.8 (~OUT3)
unnamed: J3.1, Q1.1 (G)
unnamed: J3.2, Q1.2 (S)
unnamed: J3.3, Q1.3 (D)
unnamed: J4.1, Q2.1 (G)
unnamed: J4.2, Q2.2 (S)
unnamed: J4.3, Q2.3 (D)
unnamed: J5.1, Q3.1 (G)
unnamed: J5.2, Q3.2 (S)
unnamed: J5.3, Q3.3 (D)
unnamed: J6.1, Q4.1 (G)
unnamed: J6.2, Q4.2 (S)
unnamed: J6.3, Q4.3 (D)
unnamed: JP1.2 (C), R4.1, R5.1
unnamed: R1.1, U1.15 (R-EXT)
unnamed: U1.14 (SDO), U2.2 (SDI)
unnamed: R2.1, U2.15 (R-EXT)
unnamed: U2.14 (SDO), U3.2 (SDI)
unnamed: R3.1, U3.15 (R-EXT)
VDD: C1.1, C2.1, C3.1, D1.2 (A), D2.2 (A), D3.2 (A), D4.2 (A), D5.2 (A), D6.2 (A), D7.2 (A), D8.2 (A), D9.2 (A), D10.2 (A), D11.2 (A), D12.2 (A), D13.2 (A), D14.2 (A), D15.2 (A), D16.2 (A), D17.2 (A), D18.2 (A), D19.2 (A), D20.2 (A), D21.2 (A), J1.2, U1.16 (VDD), U2.16 (VDD), U3.16 (VDD)

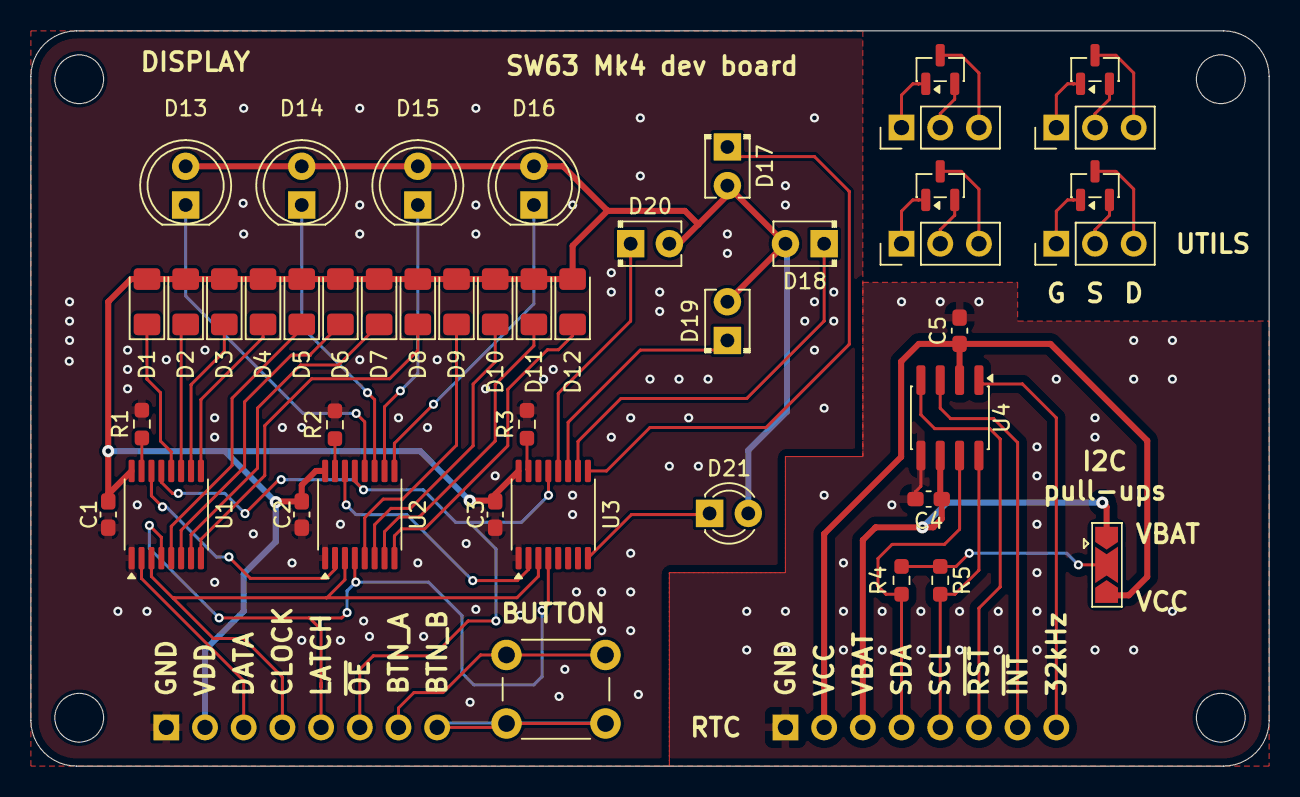
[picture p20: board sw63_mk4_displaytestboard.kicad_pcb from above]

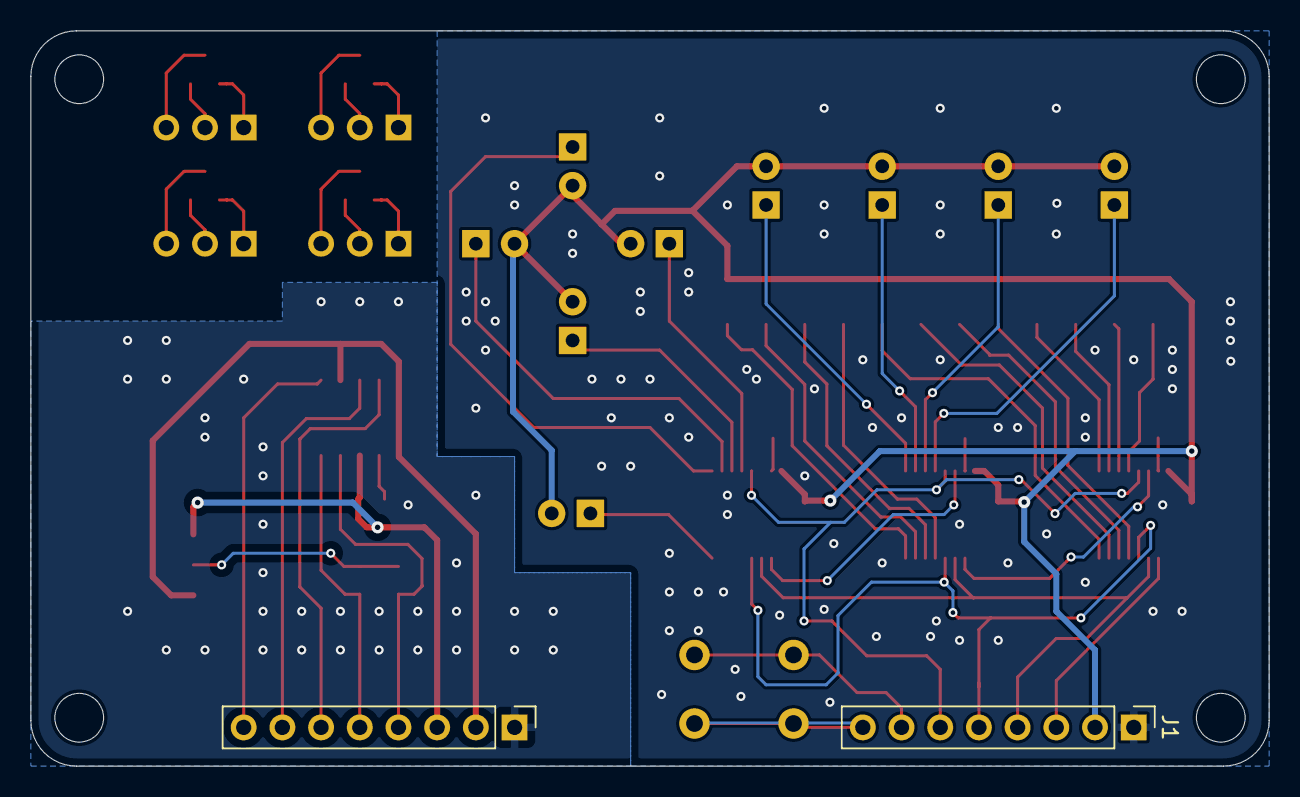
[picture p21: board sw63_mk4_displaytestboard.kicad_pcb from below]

Board: 2 copper layers, 81.3 x 48.3 mm, 51 parts (2 on the bottom side), 55 nets.

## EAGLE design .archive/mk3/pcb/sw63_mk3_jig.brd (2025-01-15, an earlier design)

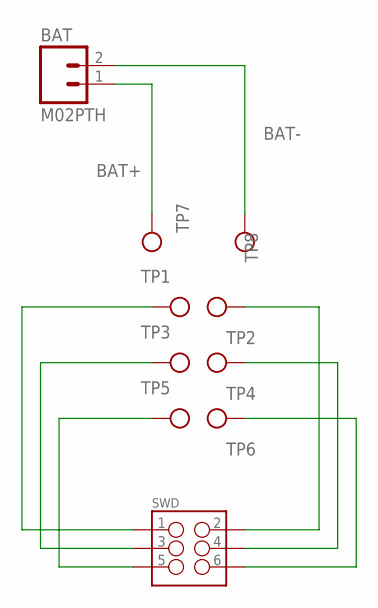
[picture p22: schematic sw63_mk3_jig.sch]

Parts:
BAT: M02PTH; 1X02
SWD: M03X2POGO_ROUND; 2X3_POGO_ROUND
TP1, TP2, TP3, TP4, TP5, TP6, TP7, TP8: R-075-SC; R-075

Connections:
BAT+: BAT.1, TP7.P$1
BAT-: BAT.2, TP8.P$1
unnamed: SWD.P$1 (1), TP1.P$1
unnamed: SWD.P$3 (3), TP3.P$1
unnamed: SWD.P$5 (5), TP5.P$1
unnamed: SWD.P$6 (6), TP6.P$1
unnamed: SWD.P$4 (4), TP4.P$1
unnamed: SWD.P$2 (2), TP2.P$1

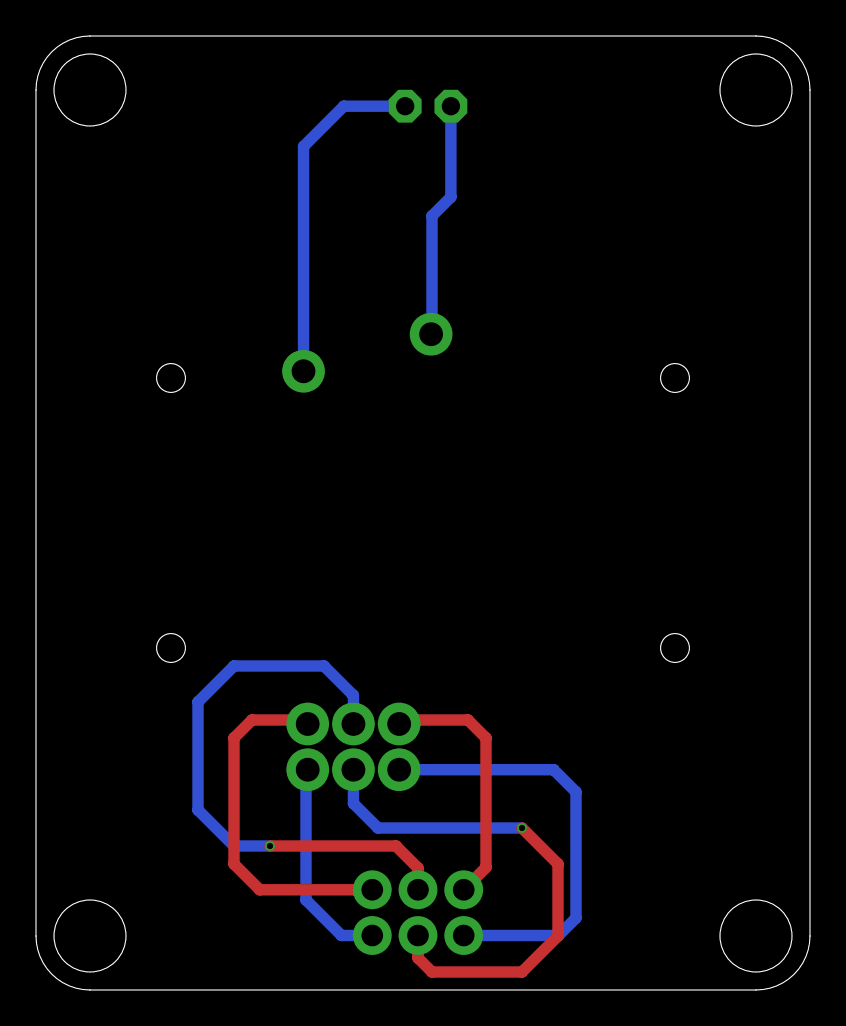
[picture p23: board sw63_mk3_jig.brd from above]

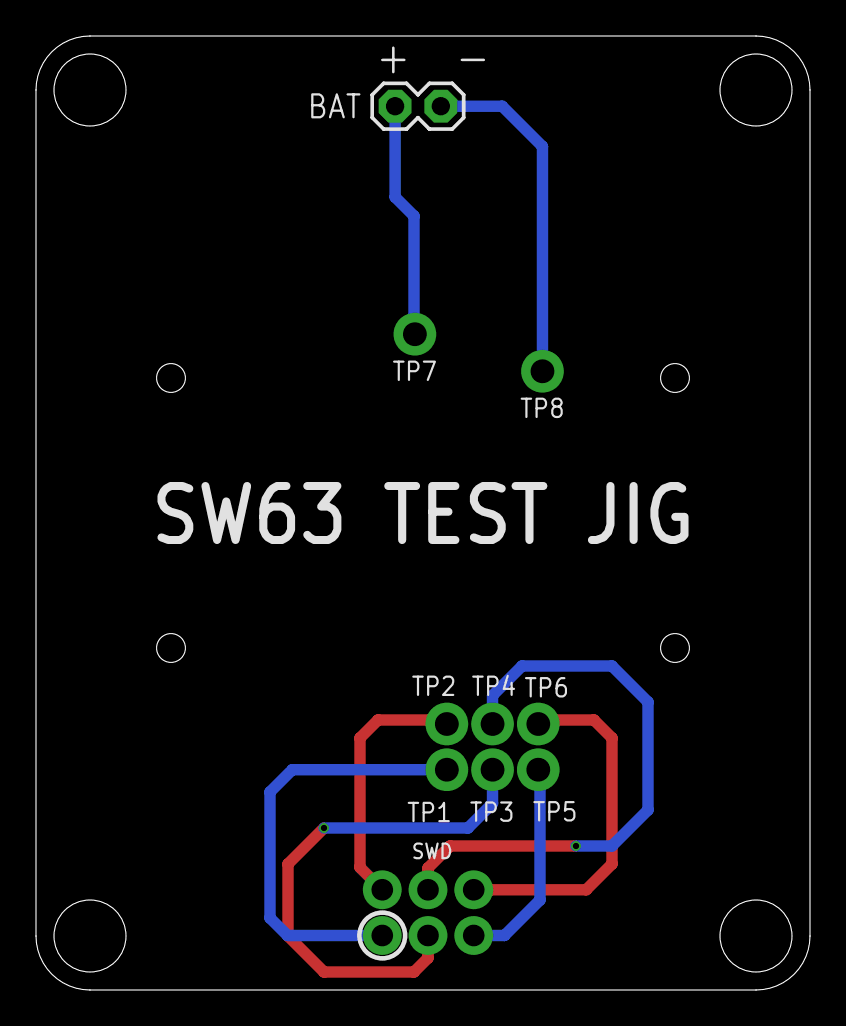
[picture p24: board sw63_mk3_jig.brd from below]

Board: 2 copper layers, 43.0 x 53.0 mm, 10 parts (10 on the bottom side), 8 nets.

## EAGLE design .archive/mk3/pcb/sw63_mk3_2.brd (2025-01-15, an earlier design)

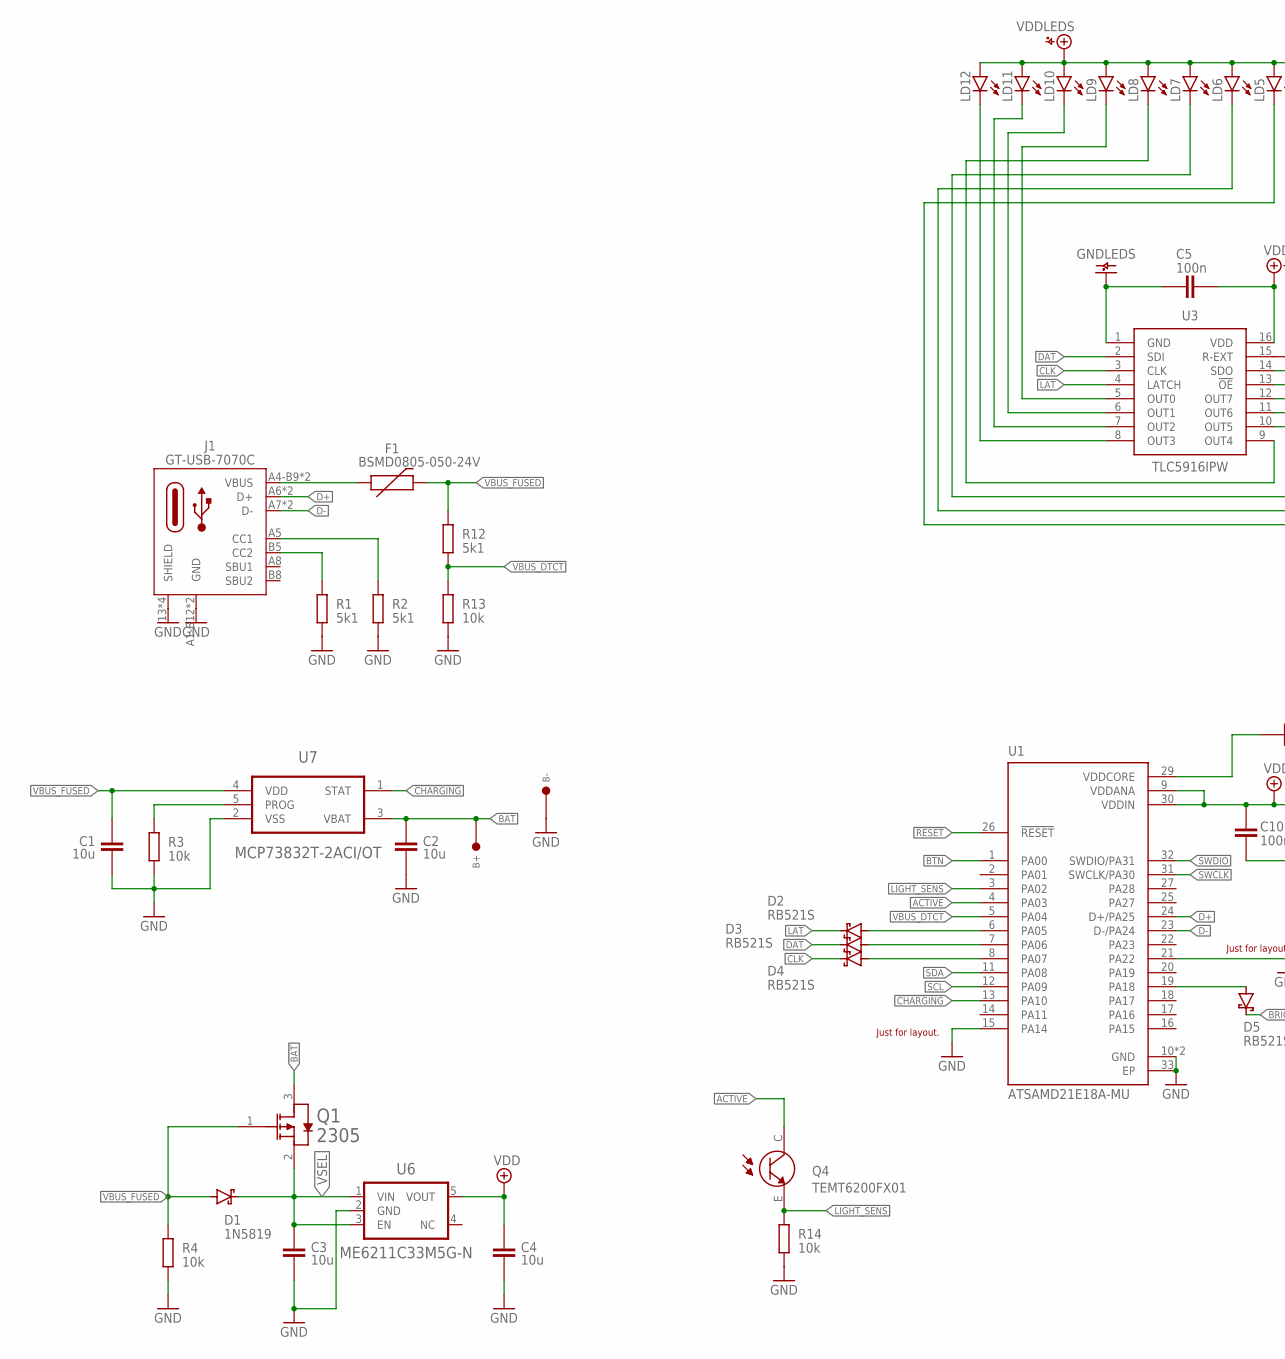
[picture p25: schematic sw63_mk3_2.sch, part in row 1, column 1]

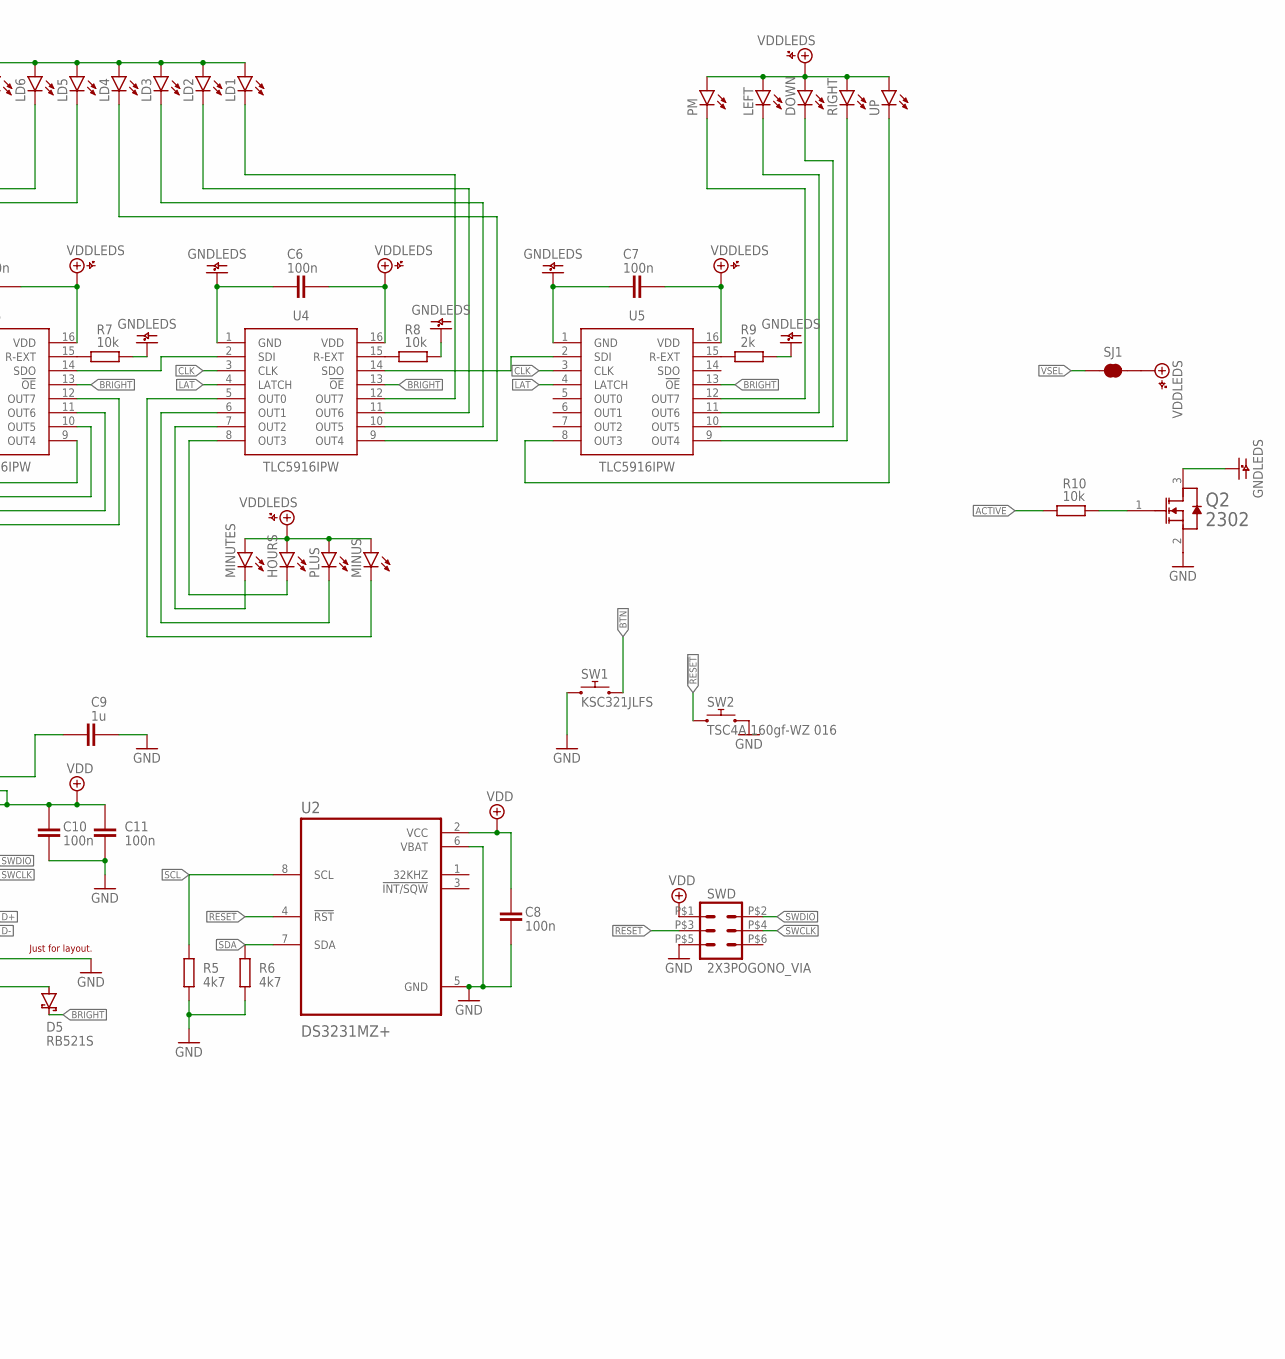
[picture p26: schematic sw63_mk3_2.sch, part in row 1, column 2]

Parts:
B+: TEST_PIN_LARGE; TEST_PIN_2.0
B-: TEST_PIN_LARGE; TEST_PIN_2.0
C1, C2, C3, C4: 10u; CAPACITOR0805
C5, C6, C7, C8, C10, C11: 100n; CAPACITOR0603
C9: 1u; CAPACITOR0603
D1: 1N5819; SOD123
D2, D3, D4, D5: RB521S; SOD523
DOWN: LED_RECT-3.2X2; LED_RECT_3.2X2
F1: BSMD0805-050-24V; PTC0805
HOURS: LED_THT-5MM_B; LED_5MM_BLUE
J1: GT-USB-7070C; USB-C_FULL_SMT_WS
LD1, LD2, LD3, LD4, LD5, LD6, LD7, LD8, LD9, LD10, LD11, LD12: LED_SMT_1206; LED_1206
LEFT: LED_RECT-3.2X2; LED_RECT_3.2X2
MINUS: LED_THT-5MM_R; LED_5MM_RED
MINUTES: LED_THT-5MM_Y; LED_5MM_YELLOW
PLUS: LED_THT-5MM_G; LED_5MM_GREEN
PM: LED_THT-3MM_ALT; LED_3MM_ALT
Q1: 2305; SOT23
Q2: 2302; SOT23
Q4: TEMT6200FX01
R1, R2, R12: 5k1; RESISTOR0603
R3, R4, R7, R8, R10, R13, R14: 10k; RESISTOR0603
R5, R6: 4k7; RESISTOR0603
R9: 2k; RESISTOR0603
RIGHT: LED_RECT-3.2X2; LED_RECT_3.2X2
SJ1: SMALL_NC; SMALL_NC_NOSILK
SW1: KSC321JLFS; KSC3XXJ
SW2: TSC4A 160gf-WZ 016; EVQ-P7J01P
SWD: 2X3POGONO_VIA; 2X3_POGO_NO_VIA
U1: ATSAMD21E18A-MU; QFN50P500X500X100-33N
U2: DS3231MZ+; SO8
U3, U4, U5: TLC5916IPW; TSSOP16
U6: ME6211C33M5G-N; SOT23-5
U7: MCP73832T-2ACI/OT; SOT23-5
UP: LED_RECT-3.2X2; LED_RECT_3.2X2

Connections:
!CHARGING: U1.13 (PA10), U7.1 (STAT)
!RESET: SW2.1_1 (1), SW2.1_2 (1), SWD.P$3 (3), U1.26 (!RESET), U2.4 (!RST)
ACTIVE: Q4.C, R10.2, U1.4 (PA03)
BAT: B+.P$1, C2.1, Q1.3 (DRAIN), U7.3 (VBAT)
BRIGHT: D5.C, U3.13 (!OE), U4.13 (!OE), U5.13 (!OE)
BTN: SW1.2, SW1.4 (2), U1.1 (PA00)
CLK: D4.C, U3.3 (CLK), U4.3 (CLK), U5.3 (CLK)
D+: J1.A6 (D+), J1.B6 (D+), U1.24 (D+/PA25)
D-: J1.A7 (D-), J1.B7 (D-), U1.23 (D-/PA24)
DAT: D3.C, U3.2 (SDI)
DBRIGHT: D5.A, U1.19 (PA18)
DCLK: D4.A, U1.8 (PA07)
DDAT: D3.A, U1.7 (PA06)
DLAT: D2.A, U1.6 (PA05)
GND: B-.P$1, C1.2, C2.2, C3.2, C4.2, C8.2, C9.1, C10.1, C11.1, J1.13 (SHIELD), J1.14 (SHIELD), J1.15 (SHIELD), J1.16 (SHIELD), J1.A1-B12 (GND), J1.B1-A12 (GND), Q2.2 (SOURCE), R1.1, R2.1, R3.1, R4.1, R5.1, R6.1, R13.1, R14.1, SW1.1, SW1.3 (1), SW2.2_1 (2), SW2.2_2 (2), SWD.P$5 (5), U1.10 (GND), U1.15 (PA14), U1.21 (PA22), U1.28 (GND), U1.33 (EP), U2.5 (GND), U2.6 (VBAT), U6.2 (GND), U7.2 (VSS)
GNDLEDS: C5.1, C6.1, C7.1, Q2.3 (DRAIN), R7.1, R8.1, R9.1, U3.1 (GND), U4.1 (GND), U5.1 (GND)
LAT: D2.C, U3.4 (LATCH), U4.4 (LATCH), U5.4 (LATCH)
LIGHT_SENS: Q4.E, R14.2, U1.3 (PA02)
unnamed: F1.2 (1), J1.A4-B9 (VBUS), J1.B4-A9 (VBUS)
unnamed: J1.B5 (CC2), R1.2
unnamed: J1.A5 (CC1), R2.2
unnamed: R3.2, U7.5 (PROG)
unnamed: LD12.C, U3.8 (OUT3)
unnamed: LD11.C, U3.7 (OUT2)
unnamed: R7.2, U3.15 (R-EXT)
unnamed: R8.2, U4.15 (R-EXT)
unnamed: R9.2, U5.15 (R-EXT)
unnamed: Q2.1 (GATE), R10.1
unnamed: U4.14 (SDO), U5.2 (SDI)
unnamed: U3.14 (SDO), U4.2 (SDI)
unnamed: PM.K (C), U5.12 (OUT7)
unnamed: DOWN.K (C), U5.10 (OUT5)
unnamed: LEFT.K (C), U5.11 (OUT6)
unnamed: RIGHT.K (C), U5.9 (OUT4)
unnamed: U5.8 (OUT3), UP.K (C)
unnamed: LD10.C, U3.6 (OUT1)
unnamed: LD9.C, U3.5 (OUT0)
unnamed: LD8.C, U3.9 (OUT4)
unnamed: LD7.C, U3.10 (OUT5)
unnamed: LD6.C, U3.11 (OUT6)
unnamed: LD5.C, U3.12 (OUT7)
unnamed: C9.2, U1.29 (VDDCORE)
unnamed: LD4.C, U4.9 (OUT4)
unnamed: LD3.C, U4.10 (OUT5)
unnamed: LD2.C, U4.11 (OUT6)
unnamed: LD1.C, U4.12 (OUT7)
unnamed: HOURS.K (C), U4.8 (OUT3)
unnamed: MINUTES.K (C), U4.7 (OUT2)
unnamed: PLUS.K (C), U4.6 (OUT1)
unnamed: MINUS.K (C), U4.5 (OUT0)
SCL: R5.2, U1.12 (PA09), U2.8 (SCL)
SDA: R6.2, U1.11 (PA08), U2.7 (SDA)
SWCLK: SWD.P$4 (4), U1.31 (SWCLK/PA30)
SWDIO: SWD.P$2 (2), U1.32 (SWDIO/PA31)
VBUS_DTCT: R12.1, R13.2, U1.5 (PA04)
VBUS_FUSED: C1.1, D1.A, F1.3 (2), Q1.1 (GATE), R4.2, R12.2, U7.4 (VDD)
VDD: C4.1, C8.1, C10.2, C11.2, SWD.P$1 (1), U1.9 (VDDANA), U1.30 (VDDIN), U2.2 (VCC), U6.5 (VOUT)
VDDLEDS: C5.2, C6.2, C7.2, DOWN.A, HOURS.A, LD1.A, LD2.A, LD3.A, LD4.A, LD5.A, LD6.A, LD7.A, LD8.A, LD9.A, LD10.A, LD11.A, LD12.A, LEFT.A, MINUS.A, MINUTES.A, PLUS.A, PM.A, RIGHT.A, SJ1.2, U3.16 (VDD), U4.16 (VDD), U5.16 (VDD), UP.A
VSEL: C3.1, D1.C, Q1.2 (SOURCE), SJ1.1, U6.1 (VIN), U6.3 (EN)

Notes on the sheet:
Just for layout.

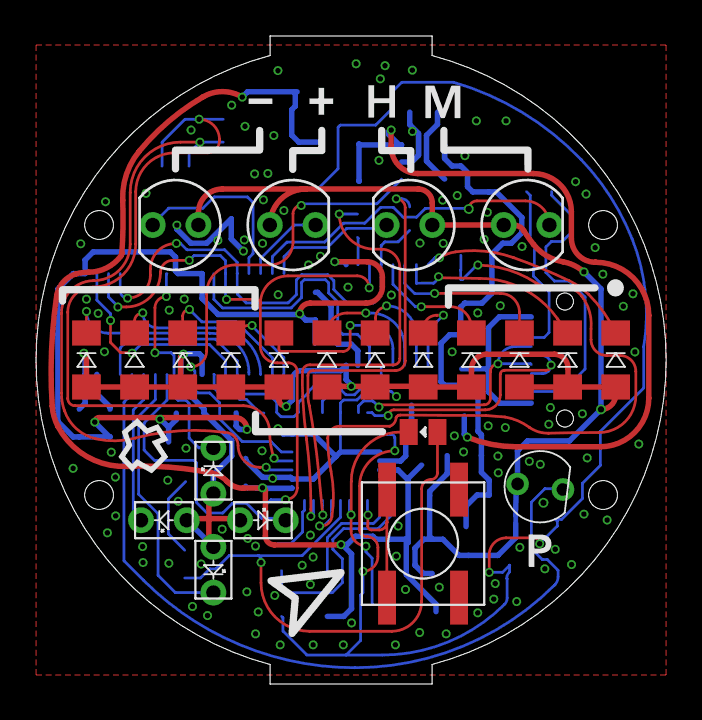
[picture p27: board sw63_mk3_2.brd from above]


Board: 2 copper layers, 35.0 x 36.0 mm, 68 parts (45 on the bottom side), 59 nets.

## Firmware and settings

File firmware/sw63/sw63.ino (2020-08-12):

// SW63 SPACEWATCH SOURCE CODE
// for MCU: ATtiny 84 (ATTinyCore) 8 MHz
// author: Vaclav Mach (vaclavmach@hotmail.cz, info@xx0x.cz)
// project homepage: www.xx0x.cz

#include <avr/interrupt.h>
#include <avr/sleep.h>

#include <DS3232RTC.h> // https://github.com/JChristensen/DS3232RTC
#include <TinyWireM.h>
#include <TimeLib.h>

#define SW63_1_0 1
#define SW63_2_0 2
#define SW63_VERSION SW63_2_0

// pin definitions - see schematic
#define PIN_ENABLE 3
#define PIN_LED_DATA 2
#define PIN_LED_CLOCK 1
#define PIN_LED_LATCH 0
#define PIN_LED_PWM 8
#define PIN_LIGHT_SENSOR A7
#define PIN_BUTTON 5

// modes
#define MODE_DISPLAY 0
#define MODE_SETTING 1
#define MODE_SECRET 2
byte mode = MODE_DISPLAY;

// display settings
#define SPEED_COUNT 6
byte currentSpeed = 0;
unsigned int speedHoldDigits[SPEED_COUNT] = {1000, 800, 600, 400, 300, 150};
unsigned int speedHold[SPEED_COUNT] = {800, 640, 480, 320, 240, 120};
unsigned int speedPause[SPEED_COUNT] = {150, 120, 90, 60, 45, 23};
unsigned int speedHoldCompressed[SPEED_COUNT] = {2000, 1600, 1200, 800, 600, 300};
#define COMPRESSED compressedActive
bool compressedActive = false;
#define SAVER saverActive
bool saverActive = false;

// how long in ms LEDs should stay on
#define HOLD_COMPRESSED speedHoldCompressed[currentSpeed]
#define HOLD_DIGITS speedHoldDigits[currentSpeed]
#define HOLD speedHold[currentSpeed]
#define PAUSE speedPause[currentSpeed]
#define SKIP 1

// language defintions
#define LANGUAGES_COUNT 5
#define CZECH 1
#define ENGLISH 2
#define GERMAN 3
#define POLISH 4
#define HUNGARIAN 5

// default language
byte language = CZECH;

// custom display class
#include "watchface/WatchFace.h"
#include "watchface/WatchFace.cpp"
WatchFace watchFace = WatchFace();

// animation definitions
#include "Animation.h"
#include "animations/AnimationExact.cpp"
#include "animations/AnimationPast.cpp"
#include "animations/AnimationTo.cpp"
#include "animations/AnimationIntro.cpp"
Animation *animation;

// button and timings
bool buttonPressed = false;
unsigned long lastTimeButton = 0;
unsigned long smashingStarted = 0;
byte smashingCount = 0;
bool ignoreNextPress = false;
bool ignoreNextLongPress = false;
#define SMASH_INTERVAL 2000
#define SMASH_COUNT 3
#define LONG_PRESS 1500
#define XLONG_PRESS 4000
#define DEBOUNCE_PRESS 50
#define BUTTON_PRESSED_NOW (!digitalRead(PIN_BUTTON))
#define SETTINGS_TIMEOUT 15000

// animation timings
unsigned long nextAnimationIsAt = 0;
unsigned long nextPauseIsAt = 0;
bool reloadTime = true;
bool paused = true;

// settings definitions
#define SETTING_STEPS 6
#define SETTING_LANGUAGE 0
#define SETTING_FACE 1
#define SETTING_HOURS 2
#define SETTING_PASTTO 3
#define SETTING_MINUTES 4
#define SETTING_PM 5
byte currentSetting = 0;

// variables for storing when setting time
byte _face = 1;
byte _hours = 1;
byte _minutes = 1;
int _pastTo = 1;
bool _pm = true;

// secret menu
bool waitForSecretMenu = false;
bool secretOpened = false;
#define SECRET_ITEMS 4
#define SECRET_SPEED 0
#define SECRET_COMPRESSED 1
#define SECRET_SAVER 2

// how often should brightness check occur
#define BRIGHTNESS_CHECK_INTERVAL 50
unsigned long lastTimeBrightnessCheck = 0;

void setup()
{
    pinMode(PIN_ENABLE, OUTPUT);
    pinMode(PIN_LED_DATA, OUTPUT);
    pinMode(PIN_LED_LATCH, OUTPUT);
    pinMode(PIN_LED_CLOCK, OUTPUT);
    pinMode(PIN_LED_PWM, OUTPUT);
    pinMode(PIN_BUTTON, INPUT_PULLUP);
    pinMode(PIN_LIGHT_SENSOR, INPUT);

    GIMSK |= _BV(PCIE0);
    PCMSK0 |= _BV(PCINT5);

    digitalWrite(PIN_ENABLE, true);

    delay(10);
    setClock(0, 0);

    delay(10);

    updateBrightness();
    showIntro();
}

void setClock(byte hr, byte min)
{
    tmElements_t tm;
    tm.Hour = hr;
    tm.Minute = min;
    tm.Second = 0;
    tm.Day = 1;
    tm.Month = 1;
    tm.Year = 1;
    RTC.write(tm);
}

void displayTimeLoop()
{
    if (reloadTime)
    {
        readTime();
        reloadTime = false;
    }
    if (!paused && nextPauseIsAt < millis() && (!buttonPressed || ignoreNextPress))
    {
        paused = true;
        watchFace.clearLeds();
        watchFace.drawLeds();
    }
    if (reloadTime || (nextAnimationIsAt < millis() && (!buttonPressed || ignoreNextPress)))
    {
        int res = animation->draw();
        watchFace.drawLeds();
        if (res > 0)
        {
            nextAnimationIsAt = millis() + res + PAUSE;
            nextPauseIsAt = millis() + res;
            paused = false;
        }
        else
        {
            reloadTime = true;
            sleep();
        }
    }
}

void settingTimeLoop()
{
    switch (currentSetting)
    {
    case SETTING_LANGUAGE:
        watchFace.updateLeds(0, 0, false, 0, language, 0, true);
        break;
    case SETTING_FACE:
        watchFace.updateLeds(0, 0, true, 0, 0, _face, 0);
        break;
    case SETTING_HOURS:
        watchFace.updateLeds(0, 0, true, 0, _hours, 0, 0);
        break;
    case SETTING_PASTTO:
        watchFace.updateLeds(_pastTo<0, _pastTo> 0, 0, true, 0, 0, 0);
        break;
    case SETTING_MINUTES:
        watchFace.updateLeds(_pastTo == -1, _pastTo == 1, 0, true, _minutes, 0, 0);
        break;
    case SETTING_PM:
        watchFace.updateLeds(0, 0, 0, 0, 0, 0, _pm);
        break;
    }
    watchFace.drawLeds();
}

void secretMenuLoop()
{
    byte val = 0;
    if (secretOpened)
    {
        switch (currentSetting)
        {
        case SECRET_SPEED:
            val = currentSpeed + 1;
            break;
        case SECRET_COMPRESSED:
            val = compressedActive ? 2 : 1;
            break;
        case SECRET_SAVER:
            val = saverActive ? 2 : 1;
            break;
        }
    }
    watchFace.updateLeds(currentSetting == 3, currentSetting == 2, currentSetting == 1, currentSetting == 0, val, 0, secretOpened);
    watchFace.drawLeds();
}

void checkForMenuExit()
{
    if (millis() - lastTimeButton > SETTINGS_TIMEOUT)
    {
        setMode(MODE_DISPLAY);
        return;
    }
}

void loop()
{
    switch (mode)
    {
    case MODE_DISPLAY:
        displayTimeLoop();
        break;
    case MODE_SETTING:
        settingTimeLoop();
        checkForMenuExit();
        break;
    case MODE_SECRET:
        secretMenuLoop();
        checkForMenuExit();
        break;
    }

    if (millis() > lastTimeBrightnessCheck + BRIGHTNESS_CHECK_INTERVAL)
    {
        updateBrightness();
        lastTimeBrightnessCheck = millis();
    }

    checkButtons();
}

/*
 * This is called when the interrupt occurs - button pressed, but we don't need to do anything in it
 */

ISR(PCINT0_vect)
{
    if (millis() - lastTimeButton < DEBOUNCE_PRESS)
    {
        return;
    }
    buttonPressed = true;
    lastTimeButton = millis();
}

/* 
 *  Doing sleep
 *  
 *  The sleep is interrupted by even shortest pressing MODE,
 *  but then there is a check, wheter the button is pressed for longer time to prevent unwanted waking-ups
 *  
 */
void sleep()
{
    watchFace.clearLeds();
    watchFace.drawLeds();
    digitalWrite(PIN_ENABLE, false);
    digitalWrite(PIN_LED_LATCH, true);
    digitalWrite(PIN_LED_DATA, true);
    digitalWrite(PIN_LED_CLOCK, true);
    digitalWrite(PIN_LED_PWM, true);

    delay(100);

    ADCSRA &= ~_BV(ADEN);
    set_sleep_mode(SLEEP_MODE_PWR_DOWN);
    sleep_enable();
    sei();
    sleep_cpu();

    // NOW WAKING UP
    cli();
    sleep_disable();
    ADCSRA |= _BV(ADEN);
    sei();

    nextAnimationIsAt = 0;
    analogWrite(PIN_LED_PWM, 254);
    digitalWrite(PIN_LED_LATCH, false);
    delay(10);
    digitalWrite(PIN_ENABLE, true);
    watchFace.clearLeds();
    watchFace.drawLeds();
    delay(PAUSE);
    lastTimeBrightnessCheck = millis();
}

bool shortButtonPress()
{
    switch (mode)
    {
    case MODE_DISPLAY:
        reloadTime = true;
        nextAnimationIsAt = 0;
        watchFace.clearLeds();
        watchFace.drawLeds();
        smashCheck();
        delay(40);
        return true;
    case MODE_SECRET:
        if (secretOpened)
        {
            switch (currentSetting)
            {
            case SECRET_SPEED:
                currentSpeed++;
                if (currentSpeed >= SPEED_COUNT)
                {
                    currentSpeed = 0;
                }
                break;
            case SECRET_COMPRESSED:
                compressedActive = !compressedActive;
                break;
            case SECRET_SAVER:
                saverActive = !saverActive;
                break;
            }
        }
        else
        {
            currentSetting++;
            if (currentSetting >= SECRET_ITEMS)
            {
                currentSetting = 0;
            }
        }
        delay(40);
        return true;
    case MODE_SETTING:
        settingsButtonClick();
        return true;
    }
    return false;
}

bool longButtonPress()
{
    switch (mode)
    {
    case MODE_SETTING:
        settingsButtonLongPress();
        return true;
    case MODE_SECRET:
        if (currentSetting == 3)
        {
            watchFace.clearLeds();
            watchFace.drawLeds();
            delay(500);
            setMode(MODE_DISPLAY);
        }
        else
        {
            secretOpened = !secretOpened;
        }
        ignoreNextPress = true;
        return true;
    }
    return false;
}

bool xlongButtonPress()
{
    switch (mode)
    {
    case MODE_DISPLAY:
        setMode(MODE_SETTING);
        ignoreNextLongPress = true;
        lastTimeButton = millis();
        return false;
    case MODE_SETTING:
        setMode(MODE_SECRET);
        return true;
    }
    return false;
}

void checkButtons()
{
    if (buttonPressed)
    {
        unsigned long diff = millis() - lastTimeButton;
        if (diff > LONG_PRESS && !ignoreNextLongPress)
        {
            buttonPressed = !longButtonPress();
        }
        if (diff > XLONG_PRESS)
        {
            buttonPressed = !xlongButtonPress();
        }
    }
    if (!BUTTON_PRESSED_NOW && buttonPressed)
    {
        if (millis() - lastTimeButton < LONG_PRESS)
        {
            if (!ignoreNextPress)
            {
                shortButtonPress();
            }
            ignoreNextPress = false;
            buttonPressed = false;
        }
        ignoreNextLongPress = false;
    }
}

void smashCheck()
{
    if (millis() < smashingStarted + SMASH_INTERVAL)
    {
        smashingCount++;
        if (smashingCount >= SMASH_COUNT)
        {
            smashingCount = 0;
            watchFace.clearLeds();
            watchFace.drawLeds();
            delay(PAUSE * 2);
            showIntro();
        }
    }
    else
    {
        smashingCount = 0;
        smashingStarted = millis();
    }
}

void settingsButtonClick()
{
    switch (currentSetting)
    {
    case SETTING_LANGUAGE:
        language++;
        if (language > LANGUAGES_COUNT)
        {
            language = 1;
        }
        break;
    case SETTING_FACE:
        _face++;
        if (_face > 4)
        {
            _face = 1;
        }
        break;

    case SETTING_HOURS:
        _hours++;
        if (_hours > 12)
        {
            _hours = 1;
        }
        break;

    case SETTING_PASTTO:
        _pastTo++;
        if (_pastTo > 1)
        {
            _pastTo = -1;
        }
        break;

    case SETTING_MINUTES:
        _minutes++;
        if (_minutes > 12)
        {
            _minutes = 1;
        }
        break;

    case SETTING_PM:
        _pm = !_pm;
        break;
    }
}

void settingsButtonLongPress()
{
    ignoreNextPress = true;
    currentSetting++;
    if (_pastTo == 0 && currentSetting == SETTING_MINUTES)
    {
        currentSetting++;
    }
    if (currentSetting == SETTING_STEPS)
    {
        finishSetTime();
        setMode(MODE_DISPLAY);
    }
}

void setMode(byte newMode)
{
    _face = 1;
    _hours = 1;
    _minutes = 1;
    _pastTo = 1;
    _pm = true;
    nextAnimationIsAt = 0;
    reloadTime = true;
    currentSetting = 0;
    ignoreNextPress = true;
    mode = newMode;
}

/**
 * Reads brightness value from the sensor and updates PWM duty cycle
 */
void updateBrightness()
{
    int val = analogRead(PIN_LIGHT_SENSOR);
#if SW63_VERSION == SW63_2_0
    val = val * 2.5; // version 2.0 uses a different light sensor
#else
    val = val * 4;
#endif
    if (val > 1023)
    {
        val = 1023;
    }
    byte bright = map(val, 0, 1023, 0, 255);
    analogWrite(PIN_LED_PWM, 255 - bright);
}

/**
 * Finishes time setting
 * Quite complicated, since each language works differently
 */
void finishSetTime()
{
    int mn = (_face - 1) * 15 + _minutes * _pastTo;
    byte hr = _hours;

    if (language == CZECH || language == HUNGARIAN)
    {
        if (_face > 1 || mn < 0)
        {
            hr--;
        }
    }
    else if (language == ENGLISH)
    {
        if (_face > 3 || mn < 0)
        {
            hr--;
        }
    }
    else if (language == GERMAN || language == POLISH)
    {
        if (_face > 2 || mn < 0)
        {
            hr--;
        }
    }

    if (mn < 0)
    {
        mn += 60;
    }

    if (_pm)
    {
        hr += 12;
    }
    if (hr == 24)
    {
        hr = 0;
    }

    delay(10);
    setClock(hr, mn);
    delay(10);
}

/**
 * Reads time from RTC and displays it
 */
void readTime()
{
    tmElements_t t;
    RTC.read(t);

    int hh = t.Hour;
    int mm = t.Minute;

    byte aftercoef = 0; // how "quarter after" modifies hours
    byte halfcoef = 0;  // how "half past" modifies hours
    byte tocoef = 0;    // "how quarter to" modifies hours

    if (language == CZECH || language == HUNGARIAN)
    {
        aftercoef = 1;
        halfcoef = 1;
        tocoef = 1;
    }
    else if (language == ENGLISH)
    {
        aftercoef = 0;
        halfcoef = 0;
        tocoef = 1;
    }
    else if (language == GERMAN || language == POLISH)
    {
        aftercoef = 0;
        halfcoef = 1;
        tocoef = 1;
    }

    byte minutes = mm;
    byte hours = hh % 12;
    bool pm = (hh >= 12);

    delete animation;

    if (minutes == 0)
    {
        animation = new AnimationExact();
        animation->setTime(hours, 0, 1, pm);
    }
    else if (minutes < 11)
    {
        animation = new AnimationPast();
        animation->setTime(hours, minutes, 1, pm);
    }
    else if (minutes < 15)
    {
        animation = new AnimationTo();
        animation->setTime(hours + aftercoef, 15 - minutes, 2, pm);
    }
    else if (minutes == 15)
    {
        animation = new AnimationExact();
        animation->setTime(hours + aftercoef, 0, 2, pm);
    }
    else if (minutes < 20)
    {
        animation = new AnimationPast();
        animation->setTime(hours + aftercoef, minutes - 15, 2, pm);
    }
    else if (minutes < 30)
    {
        animation = new AnimationTo();
        animation->setTime(hours + halfcoef, 30 - minutes, 3, pm);
    }
    else if (minutes == 30)
    {
        animation = new AnimationExact();
        animation->setTime(hours + halfcoef, 0, 3, pm);
    }
    else if (minutes < 41)
    {
        animation = new AnimationPast();
        animation->setTime(hours + halfcoef, minutes - 30, 3, pm);
    }
    else if (minutes < 45)
    {
        animation = new AnimationTo();
        animation->setTime(hours + tocoef, 45 - minutes, 4, pm);
    }
    else if (minutes == 45)
    {
        animation = new AnimationExact();
        animation->setTime(hours + tocoef, 0, 4, pm);
    }
    else if (minutes < 50)
    {
        animation = new AnimationPast();
        animation->setTime(hours + tocoef, minutes - 45, 4, pm);
    }
    else
    {
        animation = new AnimationTo();
        animation->setTime(hours + 1, 60 - minutes, 1, pm);
    }

    animation->setup();
}

/**
 * Shows intro animation which testes all diodes
 */
void showIntro()
{

    animation = new AnimationIntro();
    animation->setup();
    int waitFor = 0;
    do
    {
        waitFor = animation->drawRegular();
        watchFace.drawLeds();
        delay(waitFor);
    } while (waitFor != 0);
    watchFace.clearLeds();
    watchFace.drawLeds();
    delay(1000);
}

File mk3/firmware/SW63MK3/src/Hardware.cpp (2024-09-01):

#include "Hardware.h"

namespace SW63
{
    void Hardware::Init(voidFuncPtr button_callback, voidFuncPtr charge_callback)
    {
        InitPins(true);
        SetActive(true);
        SetBrightness(128);

        // Set up button interrupt and sleep
        byte buttonInterruptPin = digitalPinToInterrupt(PIN_BTN);
        attachInterrupt(buttonInterruptPin, button_callback, FALLING);
        byte chargeInterruptPin = digitalPinToInterrupt(PIN_CHARGING);
        attachInterrupt(chargeInterruptPin, charge_callback, FALLING);

        // enable EIC clock
        GCLK->CLKCTRL.bit.CLKEN = 0; // disable GCLK module
        while (GCLK->STATUS.bit.SYNCBUSY)
            ;

        GCLK->CLKCTRL.reg = (uint16_t)(GCLK_CLKCTRL_CLKEN | GCLK_CLKCTRL_GEN_GCLK6 | GCLK_CLKCTRL_ID(GCM_EIC)); // EIC clock switched on GCLK6
        while (GCLK->STATUS.bit.SYNCBUSY)
            ;

        GCLK->GENCTRL.reg = (GCLK_GENCTRL_GENEN | GCLK_GENCTRL_SRC_OSCULP32K | GCLK_GENCTRL_ID(6)); // source for GCLK6 is OSCULP32K
        while (GCLK->STATUS.reg & GCLK_STATUS_SYNCBUSY)
            ;

        GCLK->GENCTRL.bit.RUNSTDBY = 1; // GCLK6 run standby
        while (GCLK->STATUS.reg & GCLK_STATUS_SYNCBUSY)
            ;

        // Enable wakeup capability on pin in case being used during sleep
        EIC->WAKEUP.reg |= (1 << buttonInterruptPin);
        EIC->WAKEUP.reg |= (1 << chargeInterruptPin);
    }

    void Hardware::InitPins(bool init_interrupts)
    {
        if (init_interrupts)
        {
            pinMode(PIN_BTN, INPUT_PULLUP);
            pinMode(PIN_CHARGING, INPUT_PULLUP);
        }
        pinMode(PIN_VBUS_DTCT, INPUT);
        pinMode(PIN_ACTIVE, OUTPUT);
        pinMode(PIN_LAT, OUTPUT);
        pinMode(PIN_DAT, OUTPUT);
        pinMode(PIN_CLK, OUTPUT);
        pinMode(PIN_BRIGHTNESS, OUTPUT);
        pinMode(PIN_LIGHT_SENS, INPUT);
    }

    void Hardware::SetLeds(bool minus,
                           bool plus,
                           bool hours,
                           bool minutes,
                           uint32_t digit,
                           ClockFace face,
                           bool pm)
    {
        bitWrite(led_buffer_, BP_MINUS, minus);
        bitWrite(led_buffer_, BP_PLUS, plus);
        bitWrite(led_buffer_, BP_HOURS, hours);
        bitWrite(led_buffer_, BP_MINUTES, minutes);
        bitWrite(led_buffer_, BP_1, (digit >= 1));
        bitWrite(led_buffer_, BP_2, (digit >= 2));
        bitWrite(led_buffer_, BP_3, (digit >= 3));
        bitWrite(led_buffer_, BP_4, (digit >= 4));
        bitWrite(led_buffer_, BP_5, (digit >= 5));
        bitWrite(led_buffer_, BP_6, (digit >= 6));
        bitWrite(led_buffer_, BP_7, (digit >= 7));
        bitWrite(led_buffer_, BP_8, (digit >= 8));
        bitWrite(led_buffer_, BP_9, (digit >= 9));
        bitWrite(led_buffer_, BP_10, (digit >= 10));
        bitWrite(led_buffer_, BP_11, (digit >= 11));
        bitWrite(led_buffer_, BP_12, (digit >= 12));
        bitWrite(led_buffer_, BP_UP, face == CF_UP);
        bitWrite(led_buffer_, BP_RIGHT, face == CF_RIGHT);
        bitWrite(led_buffer_, BP_DOWN, face == CF_DOWN);
        bitWrite(led_buffer_, BP_LEFT, face == CF_LEFT);
        bitWrite(led_buffer_, BP_PM, pm);
    }

    void Hardware::ClearLeds()
    {
        led_buffer_ = 0;
    }

    void Hardware::TransferLeds()
    {
        digitalWrite(PIN_LAT, 0);
        for (uint32_t i = 0; i < 24; i++)
        {
            digitalWrite(PIN_DAT, (led_buffer_ & (1 << i)));
            digitalWrite(PIN_CLK, 1);
            digitalWrite(PIN_CLK, 0);
        }
        digitalWrite(PIN_LAT, 1);
    }

    void Hardware::SetActive(bool active)
    {
        digitalWrite(PIN_ACTIVE, active);
    }

    void Hardware::SetBrightness(uint8_t brightness)
    {
        analogWrite(PIN_BRIGHTNESS, 255 - brightness);
    }

    bool Hardware::GetButtonState()
    {
        return !digitalRead(PIN_BTN);
    }

    uint16_t Hardware::GetLightSensorValue()
    {
        return analogRead(PIN_LIGHT_SENS);
    }

    void Hardware::AutoBrightness()
    {
        // Clear LEDs to get precise light sensor value
        ClearLeds();
        TransferLeds();
        delay(5);

        // Read light sensor value
        uint16_t light = GetLightSensorValue();

        // Add more brightness for the lowest light
        light += 2;
        uint8_t brightness = map(light, 0, 1023, 1, 255);
        SetBrightness(brightness);
    }

    void Hardware::Sleep()
    {
        // Set all pins (not BUTTON) to input to reduce power consumption
        pinMode(PIN_LAT, INPUT);
        pinMode(PIN_DAT, INPUT);
        pinMode(PIN_CLK, INPUT);
        pinMode(PIN_BRIGHTNESS, INPUT);
        pinMode(PIN_LIGHT_SENS, INPUT);
        pinMode(PIN_ACTIVE, INPUT);
        pinMode(PIN_VBUS_DTCT, INPUT);
        pinMode(PIN_SCL, INPUT);
        pinMode(PIN_SDA, INPUT);

        // Wait a bit
        delay(100);
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

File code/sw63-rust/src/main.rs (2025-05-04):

#![no_std]
#![no_main]

mod ds3231;

use atsamd_hal::{
    adc::{Adc, Gain, Reference, Resolution, SampleRate},
    clock::GenericClockController,
    delay::Delay,
    gpio::v2::{Pins, B, C},
    pac::{interrupt, CorePeripherals, EIC, GCLK, NVIC},
    prelude::*,
    sercom::i2c,
    target_device::Peripherals,
    time::U32Ext,
};

use cortex_m_rt::entry;
use panic_halt as _;

use ds3231::{Time, DS3231};

#[entry]
fn main() -> ! {
    // Get peripherals
    let mut peripherals = Peripherals::take().unwrap();
    let mut core = CorePeripherals::take().unwrap();

    // Configure clocks using the internal oscillator
    let mut clocks = GenericClockController::with_internal_32kosc(
        peripherals.GCLK,
        &mut peripherals.PM,
        &mut peripherals.SYSCTRL,
        &mut peripherals.NVMCTRL,
    );

    // Configure pins
    let pins = Pins::new(peripherals.PORT);

    // Configure LED on PA23 and button on PA04
    let mut led_pin = pins.pa23.into_push_pull_output();

    // Setup delay provider
    let mut delay = Delay::new(core.SYST, &mut clocks);

    // Startup indicator
    led_pin.set_high().unwrap();
    delay.delay_ms(200u32);
    led_pin.set_low().unwrap();

    // ==================================================
    // Configure GCLK with minimal power for EIC operation
    // ==================================================

    let gclk = unsafe { &*GCLK::ptr() };

    // Configure GCLK1 to use OSC32K with minimal power
    unsafe {
        // First disable the clock generator
        gclk.genctrl.write(|w| w.id().bits(1).genen().clear_bit());
        while gclk.status.read().syncbusy().bit() {}

        // Set division factor to 32 (lower power)
        gclk.gendiv.write(|w| w.id().bits(1).div().bits(32));
        while gclk.status.read().syncbusy().bit() {}

        // Configure with OSC32K and enable in standby
        gclk.genctrl.write(|w| {
            w.id().bits(1)
             .src().osc32k()
             .idc().clear_bit()    // Disable improved duty cycle (lower power)
             .genen().set_bit()
             .runstdby().set_bit() // Must run in standby for wakeup to work
        });
        while gclk.status.read().syncbusy().bit() {}

        // Connect GCLK1 to the EIC
        gclk.clkctrl.write(|w| {
            w.id().eic()
             .gen().bits(1)
             .clken().set_bit()
        });
        while gclk.status.read().syncbusy().bit() {}
    }

    // Enable EIC peripheral clock
    peripherals.PM.apbamask.modify(|_, w| w.eic_().set_bit());

    // Get EIC access
    let eic = &peripherals.EIC;

    // Disable EIC before configuring
    eic.ctrl.write(|w| w.enable().clear_bit());
    while eic.status.read().syncbusy().bit_is_set() {}

    // Configure only the button interrupt (PA04 = EXTINT[4])
    // Use input filtering to avoid spurious wakeups
    eic.config[0].write(|w| w.sense4().fall().filten4().set_bit());

    // Only enable the one interrupt we need
    eic.intenset.write(|w| w.extint4().set_bit());

    // Only enable wakeup for the specific interrupt
    eic.wakeup.write(|w| w.wakeupen4().set_bit());

    // Enable EIC
    eic.ctrl.write(|w| w.enable().set_bit());
    while eic.status.read().syncbusy().bit_is_set() {}

    // Clear any pending interrupt
    eic.intflag.write(|w| w.extint4().set_bit());

    // Configure button pin for interrupt mode
    let button_pin = pins.pa04.into_pull_up_interrupt();

    // Set up deep sleep mode
    core.SCB.set_sleepdeep();

    // Enable the EIC interrupt in NVIC
    unsafe {
        NVIC::unmask(interrupt::EIC);
    }

    // Configure I2C pins (SDA on PA08, SCL on PA09)
    // For SERCOM0, both PA08 and PA09 need to be in Alternate C mode
    let sda = pins.pa08.into_alternate::<C>();
    let scl = pins.pa09.into_alternate::<C>();

    // Set up I2C for the DS3231 RTC
    let gclk0 = clocks.gclk0();
    let sercom0_core = clocks.sercom0_core(&gclk0).unwrap();
    let i2c = i2c::I2CMaster0::new(
        &sercom0_core,
        100.khz(),
        peripherals.SERCOM0,
        &mut peripherals.PM,
        sda,
        scl,
    );

    // Create DS3231 driver
    let mut rtc = DS3231::new(i2c);

    // Set the date and time to August 18, 2025, 04:20:00
    let time = Time {
        year: 2025,
        month: 8,
        day: 18,
        hour: 4,
        minute: 20,
        second: 0,
    };

    // Set the time on the DS3231
    if let Err(_) = rtc.set_time(&time) {
        // Handle error (just blink rapidly in this example)
        loop {
            led_pin.toggle().unwrap();
            delay.delay_ms(100u32);
        }
    }

    // Configure PA02 as an analog input
    let mut analog_pin = pins.pa02.into_alternate::<B>();

    // ADC
    let mut adc = Adc::adc(peripherals.ADC, &mut peripherals.PM, &mut clocks);
    adc.reference(Reference::INTVCC1); // Internal 1/2 VDDANA reference
    adc.resolution(Resolution::_12BIT); // 12-bit resolution
    adc.samples(SampleRate::_8); // 8 samples
    adc.gain(Gain::DIV2); // 1/2 gain

    // Blink count
    let mut blink_count = 0u32;

    // Main loop
    loop {
        blink_count += 1u32;
        led_pin.toggle().unwrap();

        // Example sensor readings
        let _current_time = rtc.get_time().unwrap();
        let _brightness: u16 = adc.read(&mut analog_pin).unwrap();

        delay.delay_ms(250u32);

        // Enter deep sleep after 8 blinks
        if blink_count >= 8 {
            // Turn LED off before sleep
            led_pin.set_low().unwrap();
            blink_count = 0;

            // Disable all peripherals to save power
            disable_peripherals(&peripherals.PM);

            // Enter sleep loop - wait for any interrupt (eg. button press)
            loop {
                // Enter standby mode (deepest sleep)
                cortex_m::asm::wfi();

                // Check if button is pressed
                if button_pin.is_low().unwrap() {
                    break;
                }
            }

            // Restore peripherals
            enable_peripherals(&peripherals.PM);
        }
    }
}

#[interrupt]
fn EIC() {
    // Clear the interrupt flag in the EIC
    unsafe {
        let eic = &(*EIC::ptr());
        // Clear interrupt for EXTINT4 (button on PA04)
        eic.intflag.modify(|_, w| w.extint4().set_bit());
    }
}
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

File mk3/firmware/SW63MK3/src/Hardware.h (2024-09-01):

#ifndef SW63_HARDWARE_H
#define SW63_HARDWARE_H

#include <Arduino.h>
#include "types.h"

namespace SW63
{
    class Hardware
    {
    public:
        enum Pins
        {
            PIN_BTN,
            PIN_UNUSED1,
            PIN_LIGHT_SENS,
            PIN_ACTIVE,
            PIN_VBUS_DTCT,
            PIN_LAT,
            PIN_DAT,
            PIN_CLK,
            PIN_SDA,
            PIN_SCL,
            PIN_CHARGING,
            PIN_UNUSED2,
            PIN_UNUSED3,
            PIN_UNUSED4,
            PIN_UNUSED5,
            PIN_UNUSED6,
            PIN_BRIGHTNESS,
        };

        enum BitPositions
        {
            BP_PM,
            BP_LEFT,
            BP_DOWN,
            BP_RIGHT,
            BP_UP,
            BP_UNUSED2,
            BP_UNUSED1,
            BP_UNUSED0,
            BP_12,
            BP_11,
            BP_10,
            BP_9,
            BP_HOURS,
            BP_MINUTES,
            BP_PLUS,
            BP_MINUS,
            BP_8,
            BP_7,
            BP_6,
            BP_5,
            BP_1,
            BP_2,
            BP_3,
            BP_4,
        };

        void Init(voidFuncPtr button_callback, voidFuncPtr charge_callback);
        void SetLeds(bool minus, bool plus, bool hours, bool minutes, uint32_t digit, ClockFace face, bool pm);
        void ClearLeds();
        void TransferLeds();
        void SetActive(bool active);
        bool GetButtonState();
        void AutoBrightness();
        void Sleep();
        bool IsCharging();
        bool IsChargerConnected();

    private:
        uint32_t led_buffer_ = 0;
        void InitPins(bool init_interrupts);
        void SetBrightness(uint8_t brightness);
        uint16_t GetLightSensorValue();
    };

}

#endif

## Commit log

2019-12-08 add schematic
2019-12-08 add charger schematic
2020-05-29 add pcb sources and 3d files
    [sw63-charging-port v26.stl, sw63-full-support-v27.stl]
2020-08-12 button handling update
2021-06-11 update readme and schematics
2021-06-11 cleanup, remove old files
    [sw63-charging-port v26.stl, sw63-full-support-v27.stl]
2024-08-12 add sw63 mk3 initial schematic + layout
    [sw63_mk3.brd, sw63_mk3.sch]
2024-08-13 finishing schematics
    [sw63_mk3.brd, sw63_mk3.sch]
2024-08-13 routing done
    [sw63_mk3.brd, sw63_mk3.sch]
2024-08-13 layout tweaks
    [sw63_mk3.brd]
2024-08-13 add graphics
    [sw63_mk3.brd]
2024-08-14 layout changes for better case compatibility
    [sw63_mk3.brd, sw63_mk3.sch]
2024-08-14 update led colors to match reality
    [sw63_mk3.brd, sw63_mk3.sch]
2024-08-14 final board touches
    [sw63_mk3.brd]
2024-08-25 board update
    [sw63_mk3.brd, sw63_mk3.sch, sw63_mk3_bom.csv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]
2024-09-01 schematic notes
    [sw63_mk3.brd, sw63_mk3.sch]
2024-09-01 animations update, add charging animation etc.
2024-11-29 3_2 in progress
    [sw63_mk3_2.brd, sw63_mk3_2.sch]
2024-11-29 3_2 update
    [sw63_mk3_2.brd, sw63_mk3_2.sch]
2025-01-15 add 3_2 board files
    [sw63_mk3_2.brd, sw63_mk3_2.sch, sw63_mk3_2_bom.csv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]
2025-05-04 cleanup, button reading
2025-05-04 implement adc reading
2025-05-04 button reading using interrupt
2026-01-26 archive old stuff
    [BOM-sw63_mk4_displaytestboard.csv, sw63_mk3.brd, sw63_mk3.sch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]
2026-01-26 begin mk4 schematic
    [BOM-sw63_mk4_displaytestboard.csv, sw63_mk4_v1.kicad_pcb, sw63_mk4_v1.kicad_sch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]
2026-01-26 layout in progress
    [sw63_mk4_v1.kicad_pcb, sw63_mk4_v1.kicad_sch]
2026-01-26 update board
    [GT-USB-7070C.step, KSC321JLFS.step, sw63_mk4_v1.kicad_pcb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]
2026-01-28 update models and footprints
    [KSC321JLFS.step, KSC3XXJ.step, LED_1206_W.step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]
2026-01-28 routing in progress
    [sw63_mk4_v1.kicad_pcb, sw63_mk4_v1.kicad_sch]
2026-01-28 routing, graphics
    [sw63_mk4_v1.kicad_pcb, sw63_mk4_v1.kicad_sch]
2026-01-28 updated models
    [sw63_mk4_v1.kicad_pcb, sw63_mk4_v1.kicad_sch]
2026-01-29 add usb dtct
    [sw63_mk4_v1.kicad_pcb, sw63_mk4_v1.kicad_sch]
2026-01-29 panelization prepare
    [sw63_mk4_v1.kicad_pcb]
2026-01-29 mfg data
    [BOM-sw63_mk4_displaytestboard.csv, BOM-sw63_mk4_v1.csv, sw63_mk4_v1.kicad_pcb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]
2026-01-30 add case graphics
    [sw63-case-graphics.dxf]
2026-02-02 update case & graphics
    [sw63-case-graphics.dxf, sw63-case.step]
2026-02-02 end charge animation when charging done
2026-02-02 add Button class
2026-02-02 update button behavior
2026-02-06 bug note
    [sw63_mk4_v1.kicad_sch]
2026-02-06 update for new wiring
2026-02-06 working charge animation
2026-02-06 slower brightness pwm to prevent glitches
2026-02-06 do auto brightness always between frames
2026-02-06 add power detection
2026-02-07 charge animation cleanup
2026-02-07 add custom System::Millis() function
2026-02-07 cleanup button
2026-02-07 low battery indication before sleep
2026-02-07 add battery level display to the secret menu
2026-02-08 invert charge complete blink cycle
2026-02-17 fix LED driver startup glitch (hopefully)
    [Display.cpp]
2026-03-07 add v2 pcb with fixed mosfet
    [BOM-sw63_mk4_v1.csv, GT-USB-7070C.step, KSC3XXJ.step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]
2026-03-07 remove v1 pcb
    [BOM-sw63_mk4_v1.csv, GT-USB-7070C.step, KSC3XXJ.step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]
2026-03-07 slightly smaller pcb, better fit in the enclosure
    [sw63_mk4_v2.kicad_pcb]
2026-03-12 updated pcb info
    [sw63_mk4_v2.kicad_pcb, sw63_mk4_v2.kicad_sch]
2026-03-12 updated production files
    [BOM-sw63_mk4_v2.csv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]
2026-03-12 remove automatic pcb backups from git
    [sw63_mk4_v2-CuBottom.gbr, sw63_mk4_v2-CuIn1.gbr, sw63_mk4_v2-CuIn2.gbr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]
2026-03-29 info button next to languages doesn't do anything now
2026-03-29 fix up language sequences for Polish
    [Locale.cpp]
2026-04-16 update part names and docs
    [sw63_mk4_v2.kicad_pcb, sw63_mk4_v2.kicad_sch]
2026-04-16 add bom
2026-04-16 update to Kicad 10
    [sw63_mk4_v2.kicad_pcb, sw63_mk4_v2.kicad_sch]
2026-04-22 nuke usb before sleep to prevent weird power draw issues
    [System.cpp, main.cpp]
2026-04-25 fix battery indication overflow
2026-04-25 add current date suffix
2026-04-25 image button actually clickable
2026-04-27 schematic notes and pdf
    [sw63_mk4_v2.kicad_sch]

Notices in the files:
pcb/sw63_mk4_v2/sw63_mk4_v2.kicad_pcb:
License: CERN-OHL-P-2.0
